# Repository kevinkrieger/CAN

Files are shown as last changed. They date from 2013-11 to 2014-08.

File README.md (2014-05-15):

Git repo for obd2-CAN board.

* obd2/ directory contains the KiCAD files
* lpcxpresso/ directory contains the files required to build firmware with lpcxpresso
* obd2_lpc1343/ is legacy directory when the 1343 was explored.
* reference/ contains CAN and obd2 and other reference material used in design
* video/ videos taken of design/build/test
* datasheets/ any datasheets of parts used or explored

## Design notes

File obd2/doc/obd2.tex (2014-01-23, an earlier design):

\documentclass{article}
% Allows control of page geometry
% Set to 1 inch margins (mla standard I guess)
\usepackage[margin=1in]{geometry}

% Graphics package
% Use it like:
% \begin{figure}[H]
% \centering
% \includegraphics[width=90mm,angle=0]{fixed_dome1.jpg}
% \caption{A simple caption}
% \label{overflow}
% \end{figure}	
\usepackage[pdftex]{graphicx}

% Allows you to include pdf documents or pages in the document
% using \includepdf[pages=2-4]{file} or whatever 
\usepackage{pdfpages}

% Self explanatory, appendix package
\usepackage{appendix}

% The listings package is used for inserting source code with highlights
\usepackage{listings}
\usepackage{color}
\lstdefinestyle{custom}{
  belowcaptionskip=1\baselineskip,
  language=bash,
  showstringspaces=false,
  basicstyle=\footnotesize\ttfamily,
  keywordstyle=\bfseries\color{green!40!black},
  commentstyle=\itshape\color{purple!40!black},
  identifierstyle=\color{blue},
  stringstyle=\color{orange},
  numberstyle=\ttfamily
}
\lstset{style=custom}

% Hyperref package is used for hyperlinking the document (ex: toc links)
\usepackage{hyperref}
\hypersetup{
    colorlinks,
    citecolor=black,
    filecolor=black,
    linkcolor=black,
    urlcolor=black
}

\usepackage{float}
\restylefloat{figure}

% Title Page
\title{CAN-obd2}
\author{Kevin Krieger}
\date{January 2014}

\begin{document}
\maketitle
\tableofcontents
\newpage

\section{History} \label{history}

\subsection{Version 1}

\begin{figure}[H]
\centering
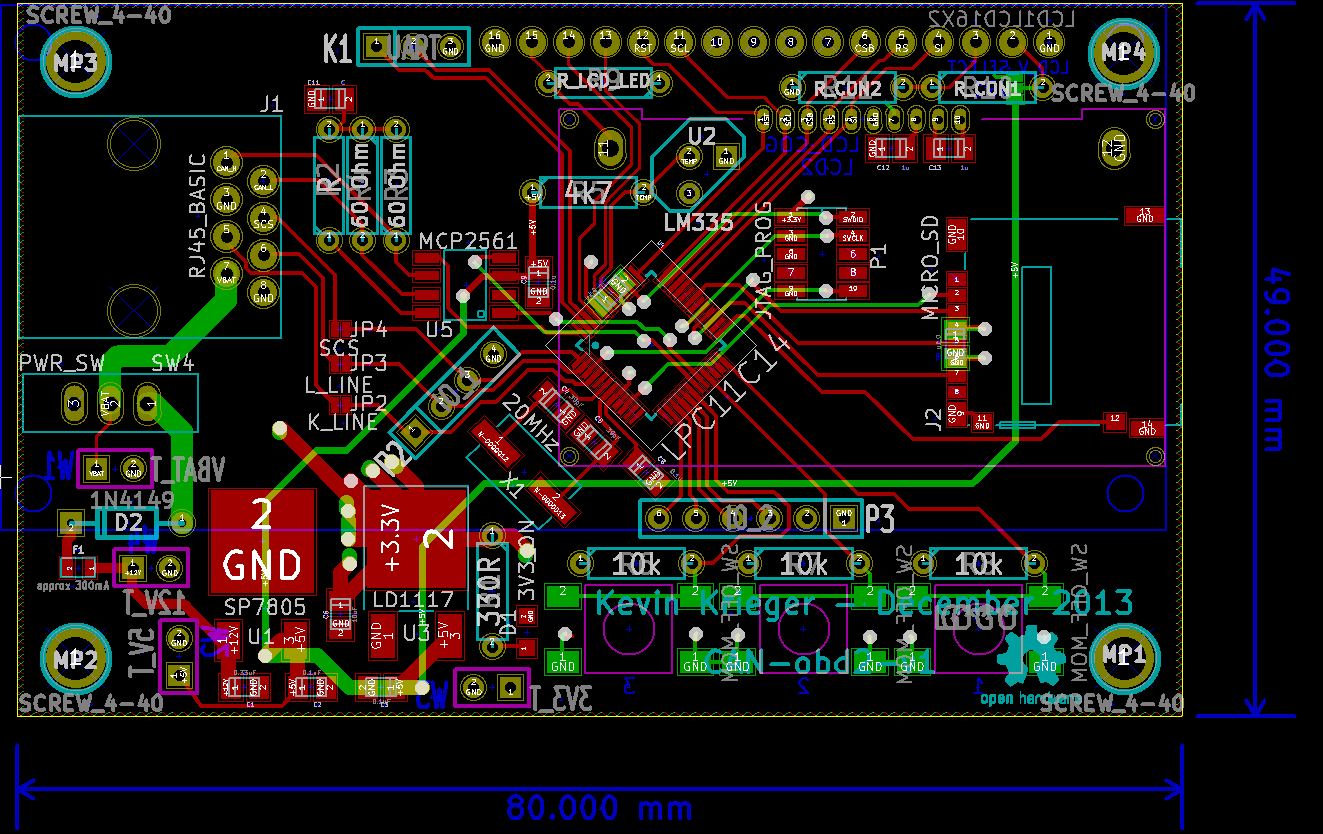
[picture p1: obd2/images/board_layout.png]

\caption{Board layout - Kicad}
\label{}
\end{figure}

\begin{figure}[H]
\centering
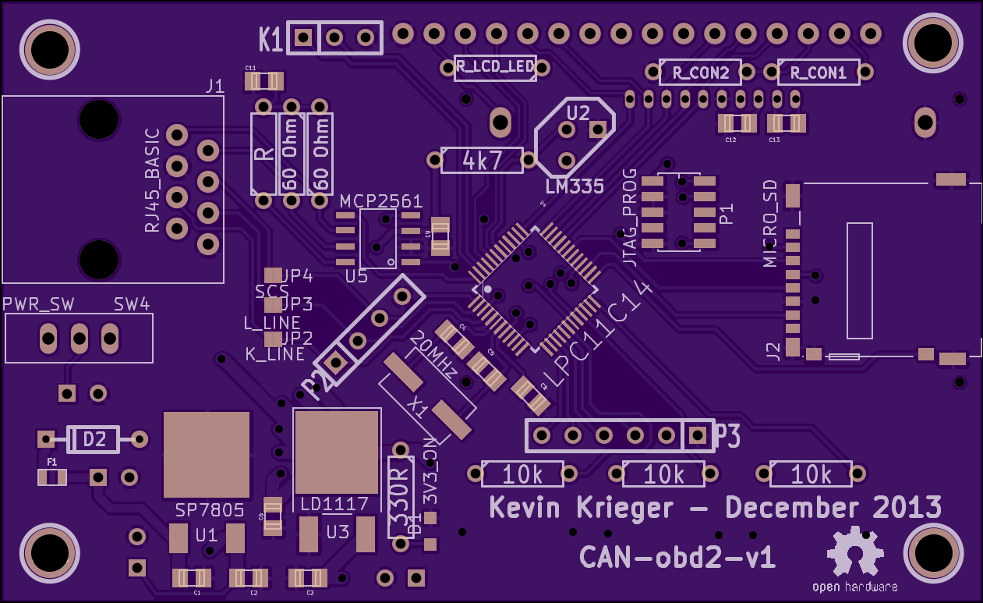
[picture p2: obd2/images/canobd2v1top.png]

\caption{oshpark.com top render}
\label{}
\end{figure}

\begin{figure}[H]
\centering
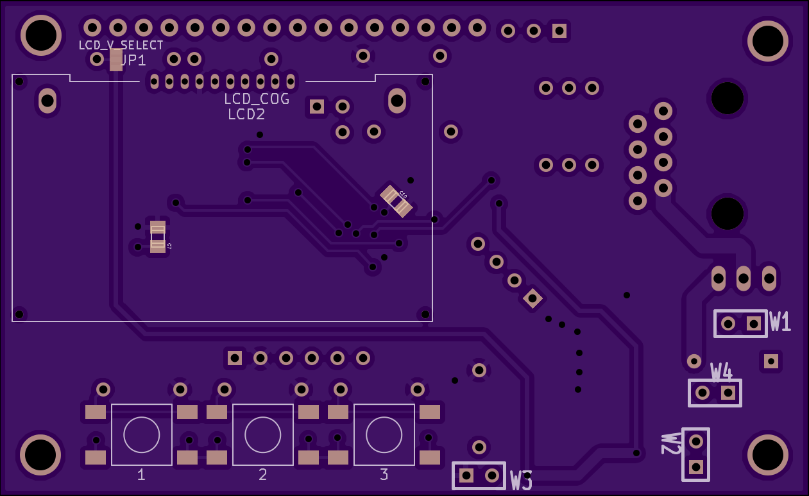
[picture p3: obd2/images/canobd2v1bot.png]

\caption{oshpark.com bottom render}
\label{}
\end{figure}

\begin{figure}[H]
\centering
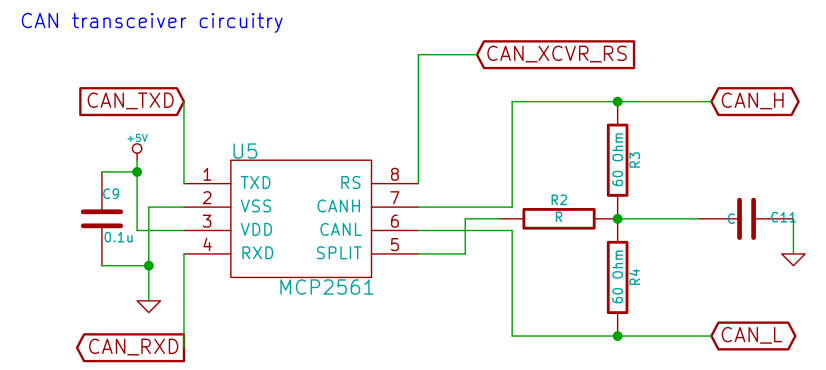
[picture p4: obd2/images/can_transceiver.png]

\caption{CAN transceiver circuitry}
\label{}
\end{figure}

\begin{figure}[H]
\centering
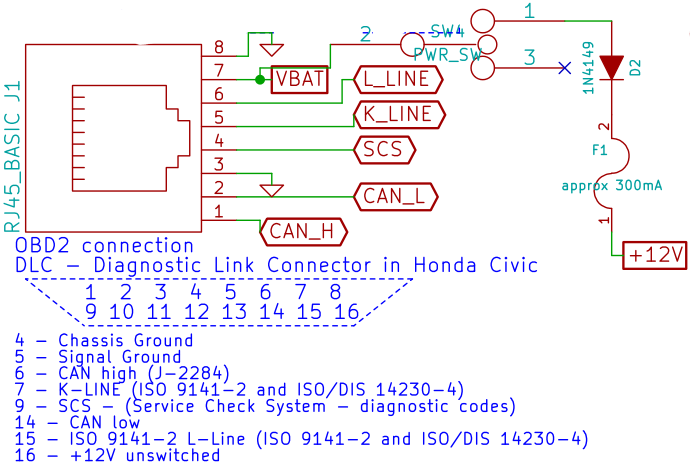
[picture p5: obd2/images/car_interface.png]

\caption{Interface to automobile data port (2008 Honda Civic)}
\label{}
\end{figure}

\begin{figure}[H]
\centering
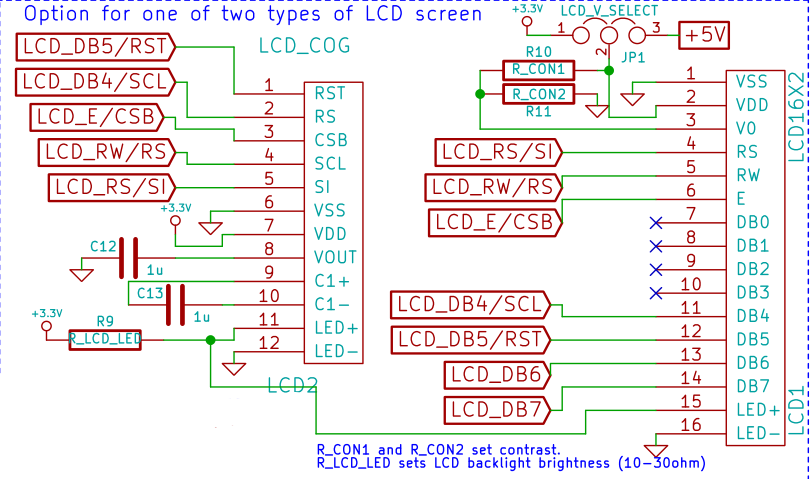
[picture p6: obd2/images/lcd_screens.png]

\caption{Two LCD screen options - circuitry}
\label{}
\end{figure}

\begin{figure}[H]
\centering
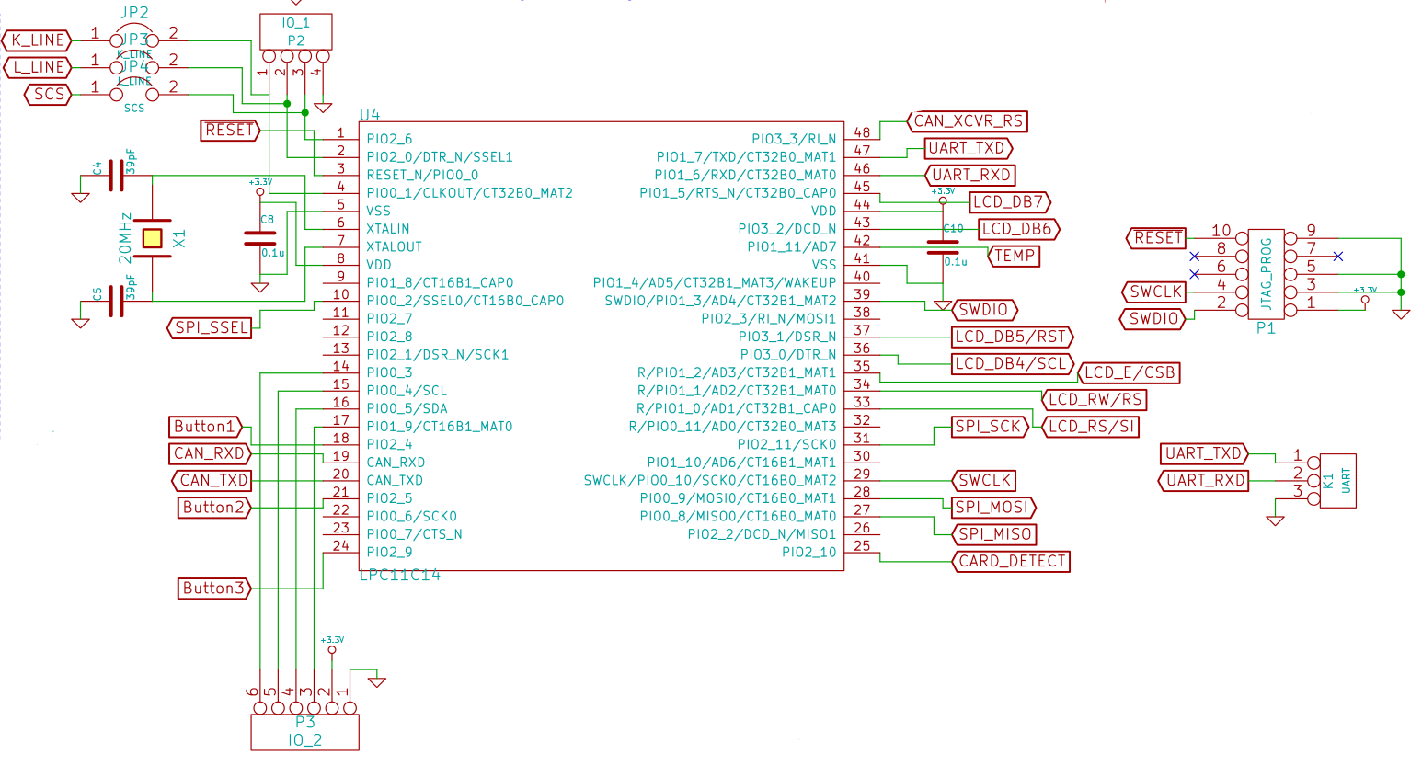
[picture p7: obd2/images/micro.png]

\caption{Microcontroller circuitry, IO connectors and programming port}
\label{}
\end{figure}

\begin{figure}[H]
\centering
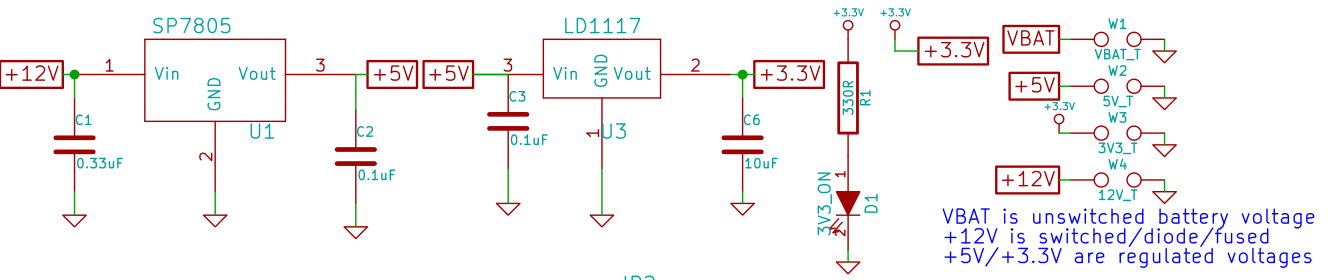
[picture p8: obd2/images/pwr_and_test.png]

\caption{Power and test point circuitry}
\label{}
\end{figure}

\begin{figure}[H]
\centering
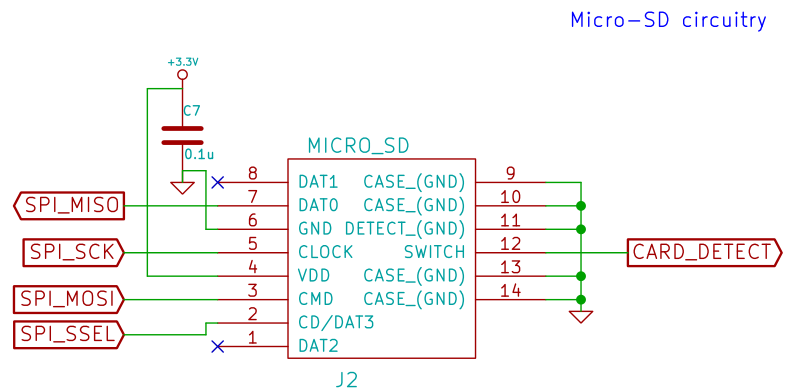
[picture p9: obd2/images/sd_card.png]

\caption{Micro SD card circuitry - SPI mode}
\label{}
\end{figure}

\begin{figure}[H]
\centering
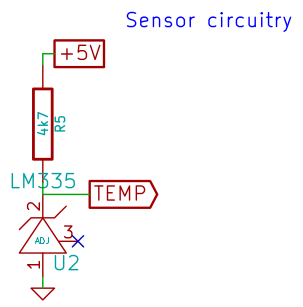
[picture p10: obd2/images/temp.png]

\caption{Temperature sensor circuit}
\label{}
\end{figure}

\begin{figure}[H]
\centering
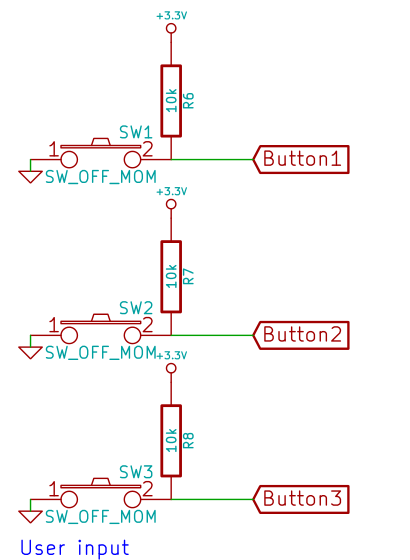
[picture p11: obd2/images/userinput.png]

\caption{User input circuitry}
\label{}
\end{figure}

\section{} \label{}

\section{} \label{}

\section{} \label{}

\section{} \label{}

\section{} \label{}

\section{} \label{}

%{%
%\newcommand{\mc}[3]{\multicolumn{#1}{#2}{#3}}
%\begin{center}
%\begin{tabular}[c]{|l|l|l|l|}\hline
%\mc{1}{|c|}{\textbf{Column 1}} & \mc{1}{c|}{\textbf{2}} & \mc{1}{c|}{\textbf%{3}} & \mc{1}{c|}{\textbf{4}}\\\hline
%Blah & Blah & blah 3 & \\
%Saskatchewan & Kevin Krieger & kevin.krieger@usask.ca & no info\\
%& & not much here &\\
%\hline
%\end{tabular}
%\end{center}
%}%

%{\bf THIS TEXT WILL BE LOUD!}

%\subsubsection{Subsubsection} \label{Labelsubsubsection}
%See the  \hyperref[overview]{Overview} section.

\appendix

\end{document}

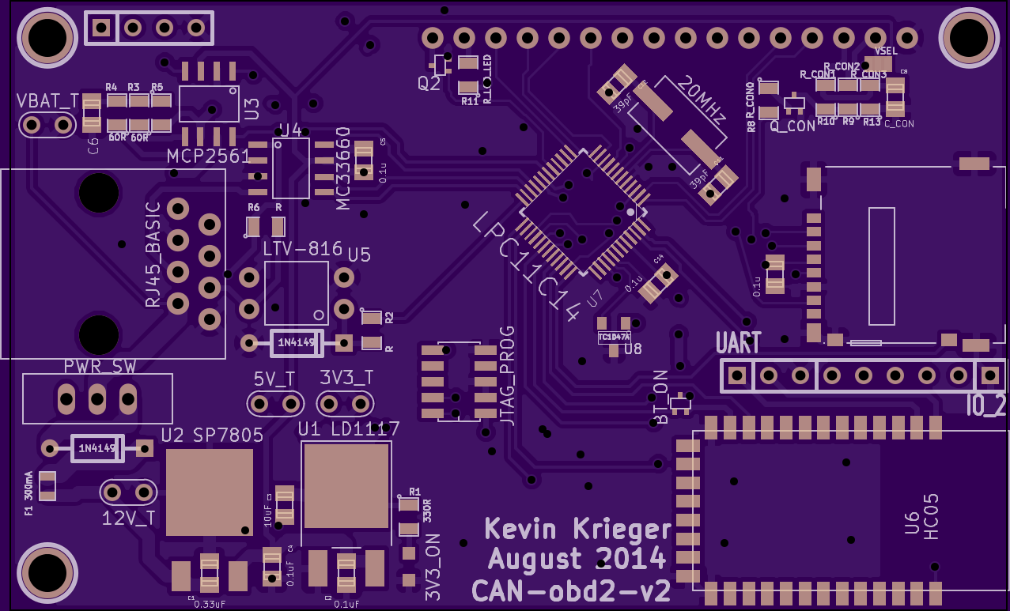
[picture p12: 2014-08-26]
obd2-v2/images/CANobd2v2_top.png

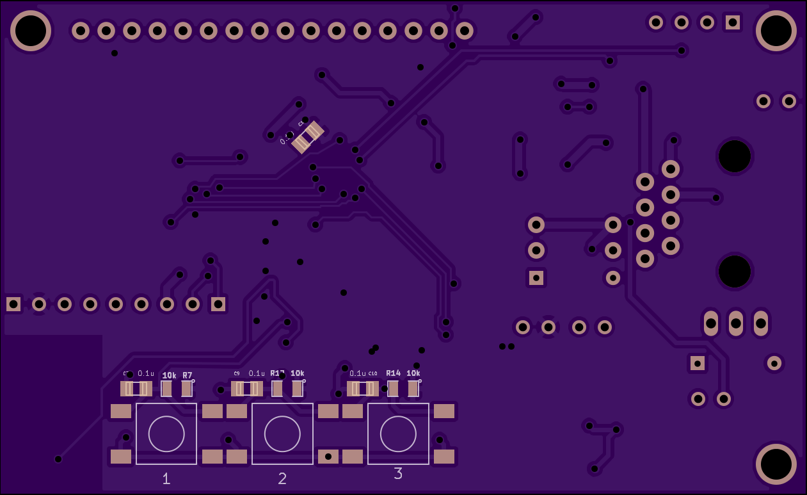
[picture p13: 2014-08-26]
obd2-v2/images/CANobd2v2_bot.png

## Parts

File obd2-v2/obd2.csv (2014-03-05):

ref | value | footprint
C1 | 0.33uF | c_0805
C2 | 0.1uF | c_0805
C3 | 0.1uF | c_0805
C4 | 39pF | c_0805
C5 | 39pF | c_0805
C6 | 10uF | c_0805
C7 | 0.1u | c_0805
C8 | 0.1u | c_0805
C9 | 0.1u | c_0805
C10 | 0.1u | c_0805
C11 | C | c_0805
C12 | 1u | c_0805
C13 | 1u | c_0805
D1 | 3V3_ON | LED_J_LEAD
D2 | 1N4149 | DO-35
F1 | approx 300mA | SM0603
J1 | RJ45_BASIC | RJ45
J2 | MICRO_SD | SD_502702_003
JP1 | LCD_V_SELECT | SOLDER_JUMPER_3
JP2 | K_LINE | SOLDER_JUMPER
JP3 | L_LINE | SOLDER_JUMPER
JP4 | SCS | SOLDER_JUMPER
K1 | UART | SIL-3
LCD1 | LCD16X2 | GDM1602K
LCD2 | LCD_COG | NHD_C0216CZ_NSW_BBW
MP1 | SCREW_4-40 | 1pin
MP2 | SCREW_4-40 | 1pin
MP3 | SCREW_4-40 | 1pin
MP4 | SCREW_4-40 | 1pin
P1 | JTAG_PROG | GRPB052VWQS-RC
P2 | IO_1 | SIL-4
P3 | IO_2 | SIL-6
R1 | 330R | R3
R2 | R | R3
R3 | 60 Ohm | R3
R4 | 60 Ohm | R3
R5 | 4k7 | R3
R6 | 10k | R3
R7 | 10k | R3
R8 | 10k | R3
R9 | R_LCD_LED | R3
R10 | R_CON1 | R3
R11 | R_CON2 | R3
SW1 | SW_OFF_MOM | FSM4JSMA_pushbutton
SW2 | SW_OFF_MOM | FSM4JSMA_pushbutton
SW3 | SW_OFF_MOM | FSM4JSMA_pushbutton
SW4 | PWR_SW | MMS1208
U1 | SP7805 | TO-252-3
U2 | LM335 | TO92
U3 | LD1117 | DPAK
U4 | LPC11C14 | LQFP48
U5 | MCP2561 | SOIC-8-Narrow
W1 | VBAT_T | SIL-2
W2 | 5V_T | SIL-2
W3 | 3V3_T | SIL-2
W4 | 12V_T | SIL-2
X1 | 20MHz | CSM-3X

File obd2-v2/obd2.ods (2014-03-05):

ref | value | footprint | part | Notes
C1 | 0.33uF | c_0805 | CC0805KKX7R8BB105 | don't have a .33uF, so use 1uF
C2 | 0.1uF | c_0805 | CL21F104ZBCNNNC
C3 | 0.1uF | c_0805 | CL21F104ZBCNNNC
C4 | 39pF | c_0805 | CL21C390JBANNNC
C5 | 39pF | c_0805 | CL21C390JBANNNC
C6 | 10uF | c_0805 | LMK212B7106KG-TD
C7 | 0.1u | c_0805 | CL21F104ZBCNNNC
C8 | 0.1u | c_0805 | CL21F104ZBCNNNC
C9 | 0.1u | c_0805 | CL21F104ZBCNNNC
C10 | 0.1u | c_0805 | CL21F104ZBCNNNC
C11 | C | c_0805 |  | Don't populate unless you need to
C12 | 1u | c_0805 | CC0805KKX7R8BB105 | Don't populate unless using GDM1602K
C13 | 1u | c_0805 | CC0805KKX7R8BB105 | Don't populate unless using GDM1602K
D1 | 3V3_ON | LED_J_LEAD | LG M67K-G1J2-24-Z | Don't populate unless using GDM1602K
D2 | 1N4149 | DO-35 | 1N4149TR
F1 | approx 300mA | SM0603 | 0603SFV050F/32-2CT-ND | it's 500mA, which should be PLENTY
J1 | RJ45_BASIC | RJ45 | 54602-908LF
J2 | MICRO_SD | SD_502702_003 | 5027020891 | the pads could be a bit larger away from the body of the device.
JP1 | LCD_V_SELECT | SOLDER_JUMPER_3
JP2 | K_LINE | SOLDER_JUMPER
JP3 | L_LINE | SOLDER_JUMPER
JP4 | SCS | SOLDER_JUMPER
K1 | UART | SIL-3
LCD1 | LCD16X2 | GDM1602K |  | Definitely need the A and K pins to be wider, and the rest of the pins should be a bit bigger. I used a hobby knife to cut them down to size a bit. *** THE A/K pins ARE OK, BUT THE OTHERS ARE ALL BACKWARDS!!! ***
LCD2 | LCD_COG | NHD_C0216CZ_NSW_BBW
MP1 | SCREW_4-40 | 1pin
MP2 | SCREW_4-40 | 1pin
MP3 | SCREW_4-40 | 1pin
MP4 | SCREW_4-40 | 1pin
P1 | JTAG_PROG | GRPB052VWQS-RC | FFSD-05-D-06.00-01-N
P2 | IO_1 | SIL-4
P3 | IO_2 | SIL-6
R1 | 330R | R3
R2 | R | R3 |  | Don't populate unless you need to
R3 | 60 Ohm | R3 | MFR-25FBF52-59R | Couldn't find 60 ohm, so 59 ohm is where it's at.
R4 | 60 Ohm | R3 | MFR-25FBF52-59R | Couldn't find 60 ohm, so 59 ohm is where it's at.
R5 | 4k7 | R3 |  | Actually using 5.6K
R6 | 10k | R3 |  | Don't populate unless you need to
R7 | 10k | R3 |  | Don't populate unless you need to
R8 | 10k | R3 |  | Don't populate unless you need to
R9 | R_LCD_LED | R3 |  | Using 18Ohm to start, sets LED backlight brightness.
R10 | R_CON1 | R3 |  | Don't populate unless using 16 pin LCD
R11 | R_CON2 | R3 |  | Don't populate unless using 16 pin LCD
SW1 | SW_OFF_MOM | FSM4JSMA_pushbutton | FSM4JSMA
SW2 | SW_OFF_MOM | FSM4JSMA_pushbutton | FSM4JSMA
SW3 | SW_OFF_MOM | FSM4JSMA_pushbutton | FSM4JSMA
SW4 | PWR_SW | MMS1208 | MMS1208
U1 | SP7805 | TO-252-3 | SP7805V2-L/TR
U2 | LM335 | TO92 | SEN-09438
U3 | LD1117 | DPAK | LD1117DT33TR
U4 | LPC11C14 | LQFP48 | lpc11c14
U5 | MCP2561 | SOIC-8-Narrow | mcp256
W1 | VBAT_T | SIL-2
W2 | 5V_T | SIL-2
W3 | 3V3_T | SIL-2
W4 | 12V_T | SIL-2
X1 | 20MHz | CSM-3X | ECS-200-20-3X-EN-TR | takes 39pF capacitors

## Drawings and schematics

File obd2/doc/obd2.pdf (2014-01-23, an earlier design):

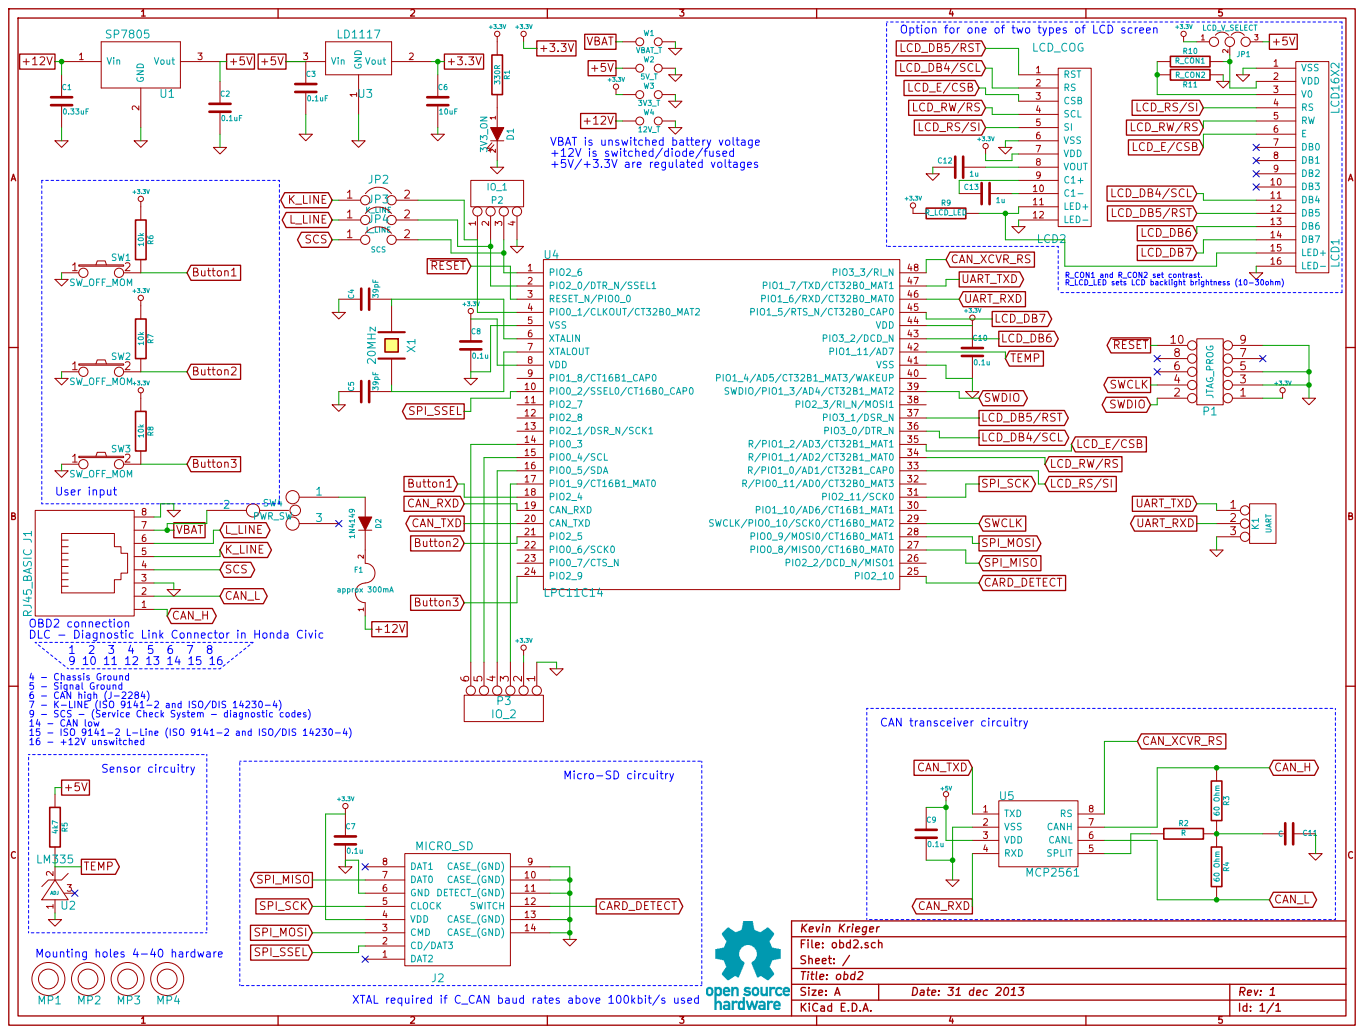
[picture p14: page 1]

+3.3V Option for one of two types of LCD screen
LCD_DB5/RST
LCD_DB4/SCL
LCD_E/CSB

R10 R_CON1 R11 R_CON2 R_CON1 and R_CON2 set contrast. R_LCD_LED sets LCD backlight brightness (10-30ohm) VBAT is unswitched battery voltage

+12V is switched/diode/fused

OBD2 connection
DLC - Diagnostic Link Connector in Honda Civic

4 - Chassis Ground
5 - Signal Ground
6 - CAN high (J-2284)
7 - K-LINE (ISO 9141-2 and ISO/DIS 14230-4)
9 - SCS - (Service Check System - diagnostic codes) 14 - CAN low

Sensor circuitry

Micro-SD circuitry

Id: 1/1 Title: obd2 File: obd2.sch Sheet: /

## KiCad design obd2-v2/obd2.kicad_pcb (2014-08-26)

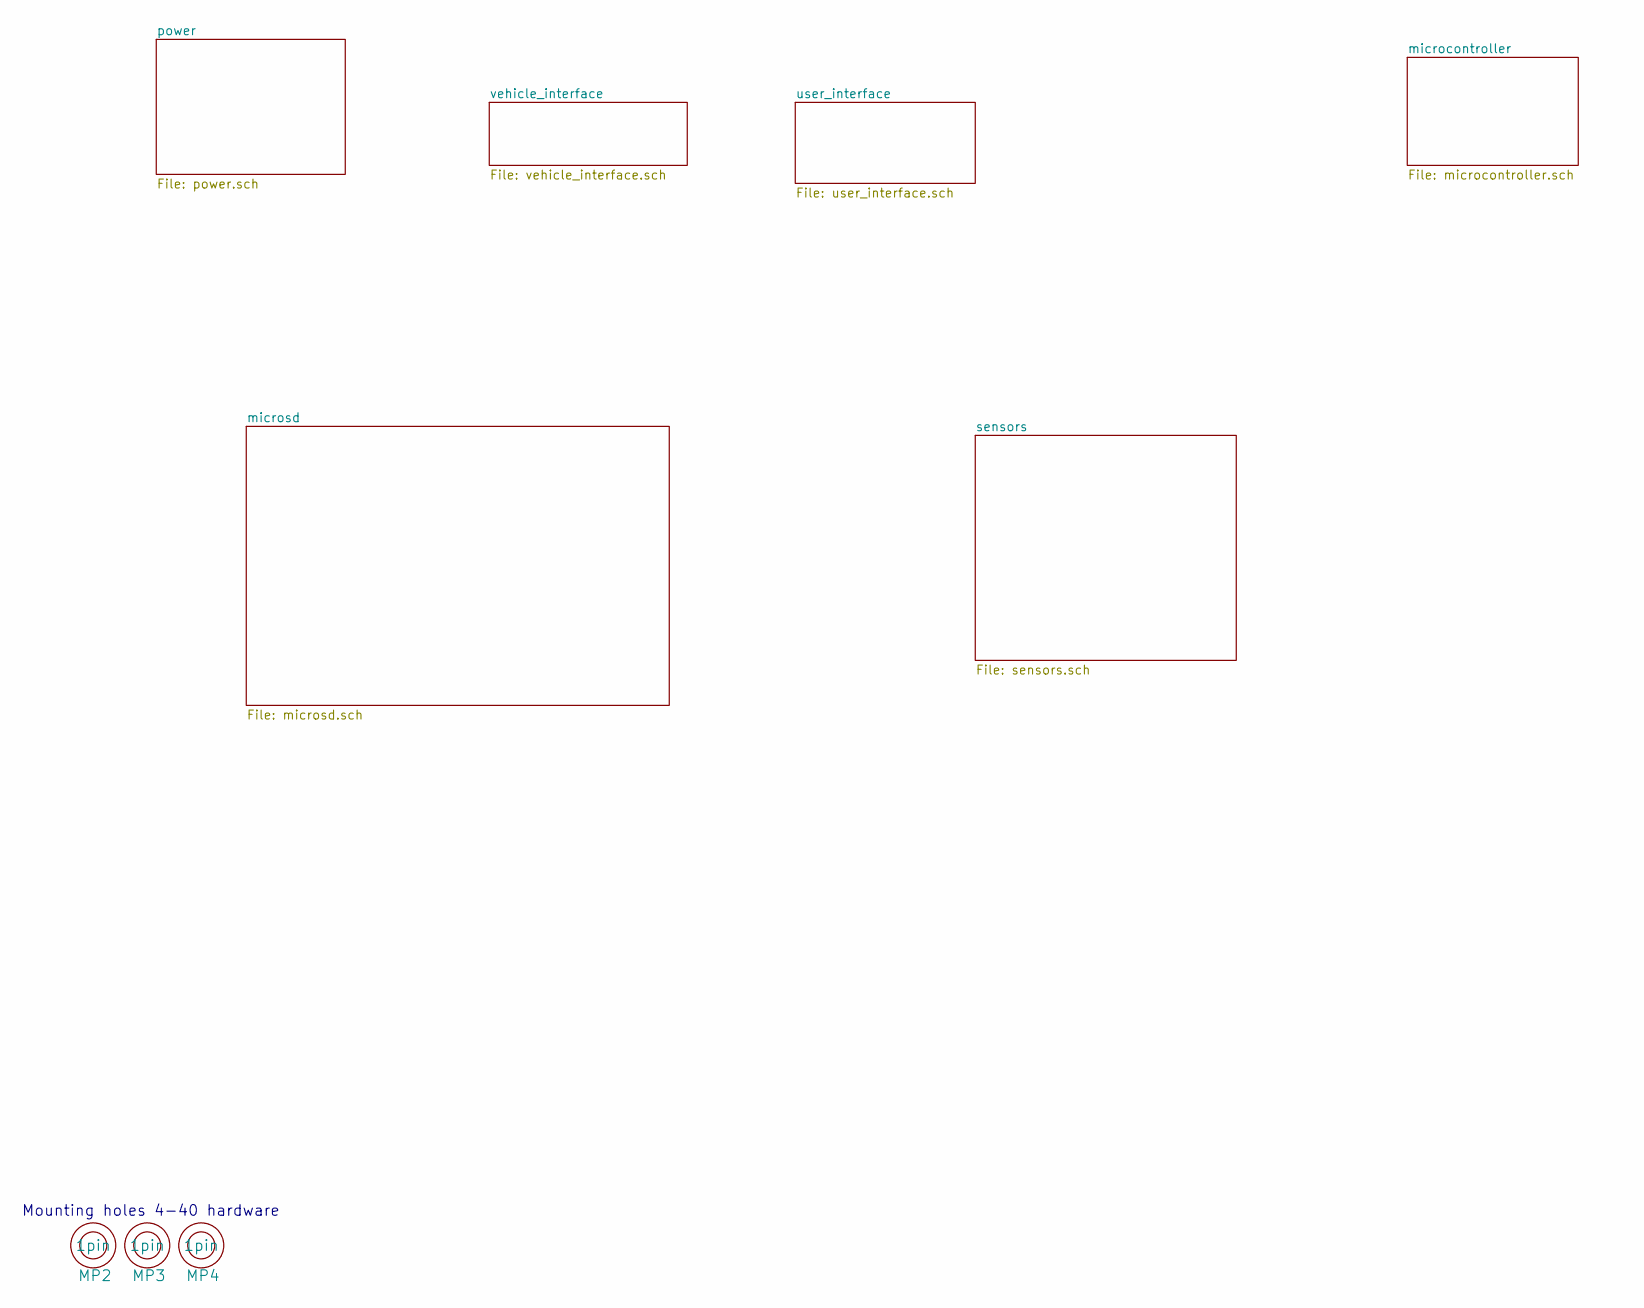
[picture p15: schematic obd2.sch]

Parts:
MP2, MP3, MP4: SCREW_4-40; 1pin

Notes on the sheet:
Mounting holes 4-40 hardware

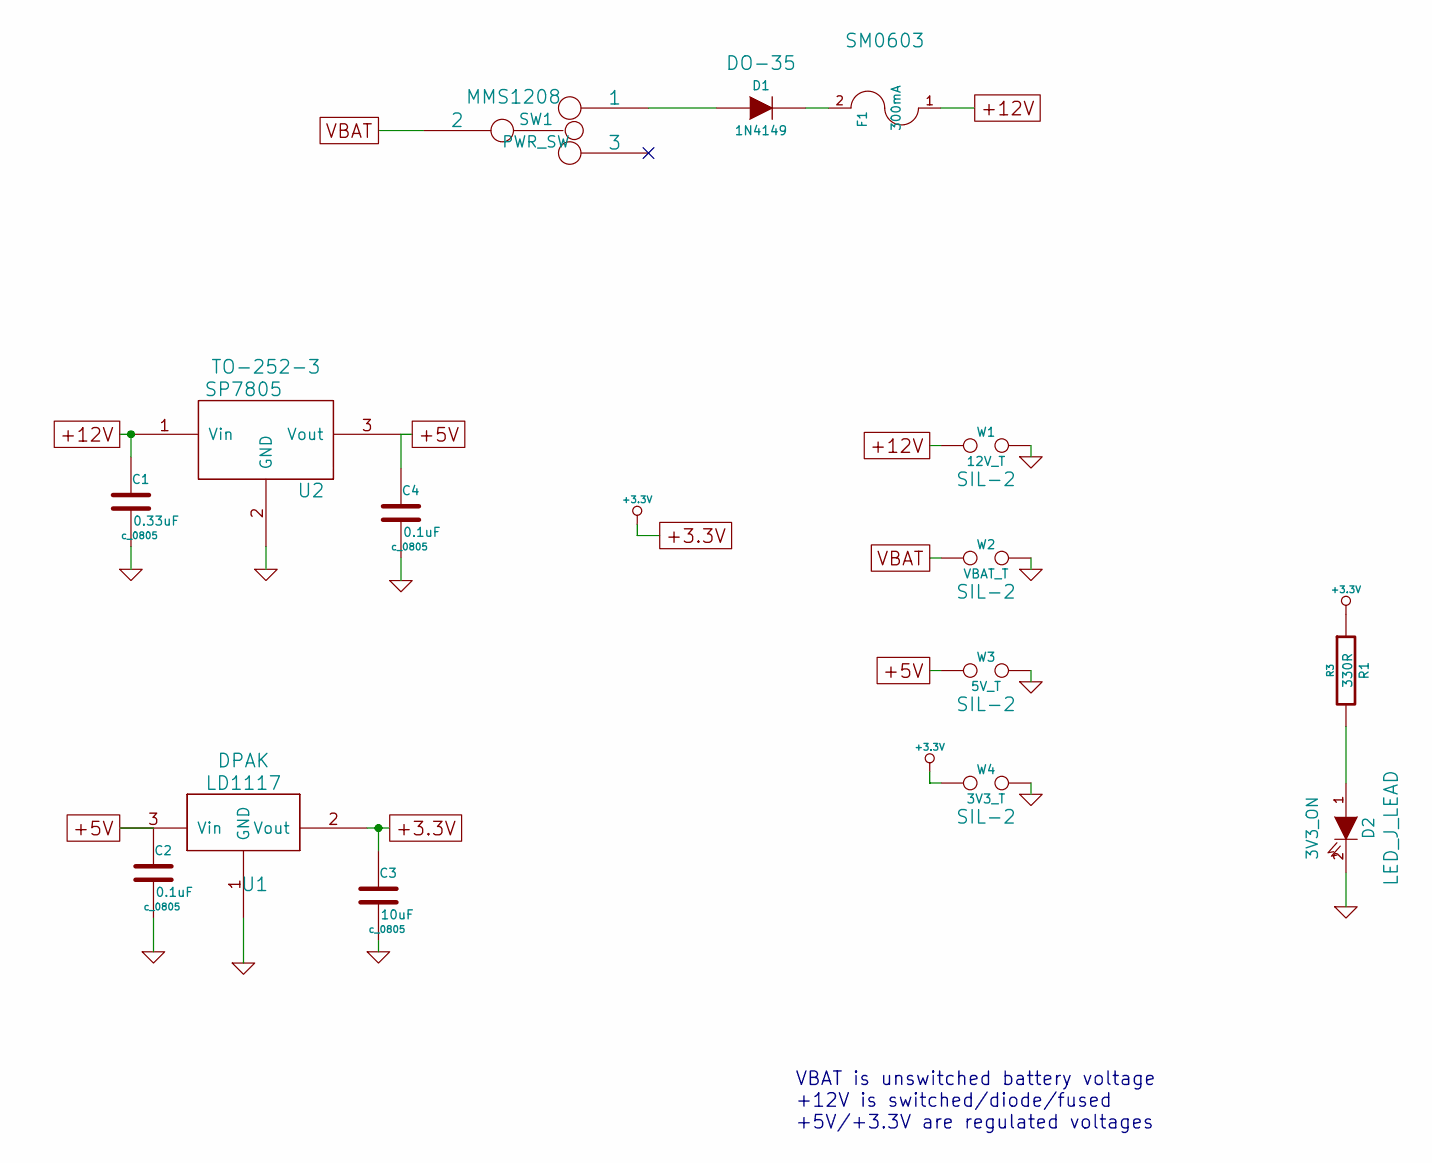
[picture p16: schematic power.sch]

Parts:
C1: 0.33uF; c_0805
C2, C4: 0.1uF; c_0805
C3: 10uF; c_0805
D1: 1N4149; DO-35
D2: 3V3_ON; LED_J_LEAD
F1: 300mA; SM0603
R1: 330R; R3
SW1: PWR_SW; MMS1208
U1: LD1117; DPAK
U2: SP7805; TO-252-3
W1: 12V_T; SIL-2
W2: VBAT_T; SIL-2
W3: 5V_T; SIL-2
W4: 3V3_T; SIL-2

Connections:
+3.3V: C3.1, R1.1, U1.2 (Vout), W4.1; also elsewhere on the board
+5V: C2.1, C4.1, U1.3 (Vin), U2.3 (Vout), W3.1; also elsewhere on the board
+12V: C1.1, F1.1, U2.1 (Vin), W1.1; also elsewhere on the board
GND: C1.2, C2.2, C3.2, C4.2, D2.2 (K), U1.1 (GND), U2.2 (GND), W1.2, W2.2, W3.2, W4.2; also elsewhere on the board
unnamed: D1.2 (K), F1.2
unnamed: D1.1 (A), SW1.1
unnamed: D2.1 (A), R1.2
VBAT: SW1.2, W2.1; also elsewhere on the board

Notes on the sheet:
VBAT is unswitched battery voltage +12V is switched/diode/fused +5V/+3.3V are regulated voltages

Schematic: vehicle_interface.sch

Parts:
C5: 0.1u; c_0805
C6: C; c_0805
D3: 1N4149
J1: RJ45_BASIC; RJ45
R2, R6: R
R3: R; R3
R4, R5: 60R; R3
U3: MCP2561; SOIC-8-Narrow
U4: MC33660
U5: LTV-816

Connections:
+5V: C5.1, U3.3 (VDD), U4.7 (VDD); also elsewhere on the board
+12V: R6.1, U4.1 (VBB); also elsewhere on the board
CAN_H: J1.1, R4.1, U3.7 (CANH)
CAN_L: J1.2, R5.2, U3.6 (CANL)
CAN_RXD: U3.4 (RXD); also elsewhere on the board
CAN_TXD: U3.1 (TXD); also elsewhere on the board
CAN_XCVR_RS: U3.8 (RS); also elsewhere on the board
GND: C5.2, C6.1, D3.1 (A), J1.3, J1.8, U3.2 (VSS), U4.3 (GND), U5.2 (K), U5.3 (E); also elsewhere on the board
K_LINE: J1.5, U4.4 (ISO)
K_LINE_EN: U4.8 (CEN); also elsewhere on the board
K_LINE_RX: U4.6 (RX); also elsewhere on the board
K_LINE_TX: U4.5 (TX); also elsewhere on the board
L_LINE: J1.6, R6.2, U5.4 (C)
L_LINE_CONTROL: R2.1; also elsewhere on the board
unnamed: D3.2 (K), R2.2, U5.1 (A)
unnamed: C6.2, R3.2, R4.2, R5.1
unnamed: R3.1, U3.5 (SPLIT)
VBAT: J1.7; also elsewhere on the board

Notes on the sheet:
OBD2 connection DLC - Diagnostic Link Connector in Honda Civic
1 2 3 4 5 6 7 8 9 10 11 12 13 14 15 16
4 - Chassis Ground 5 - Signal Ground 6 - CAN high (J-2284) 7 - K-LINE (ISO 9141-2 and ISO/DIS 14230-4) 9 - SCS - (Service Check System - diagnostic codes) 14 - CAN low 15 - ISO 9141-2 L-Line (ISO 9141-2 and ISO/DIS 14230-4) 16 - +12V unswitched
60 Ohm termination resistors only populated if board is end of CAN bus
L-line is unidirectional and used for initialization only. Optoisolation isolates the vehicle's L-Line from the microcontroller. Diode protects optoisolator from reverse voltages. See "INITIALIZING COMMUNICATION TO VEHICLE OBDII SYSTEM" by Peter Dzhelekarski, Dimiter Alexiev

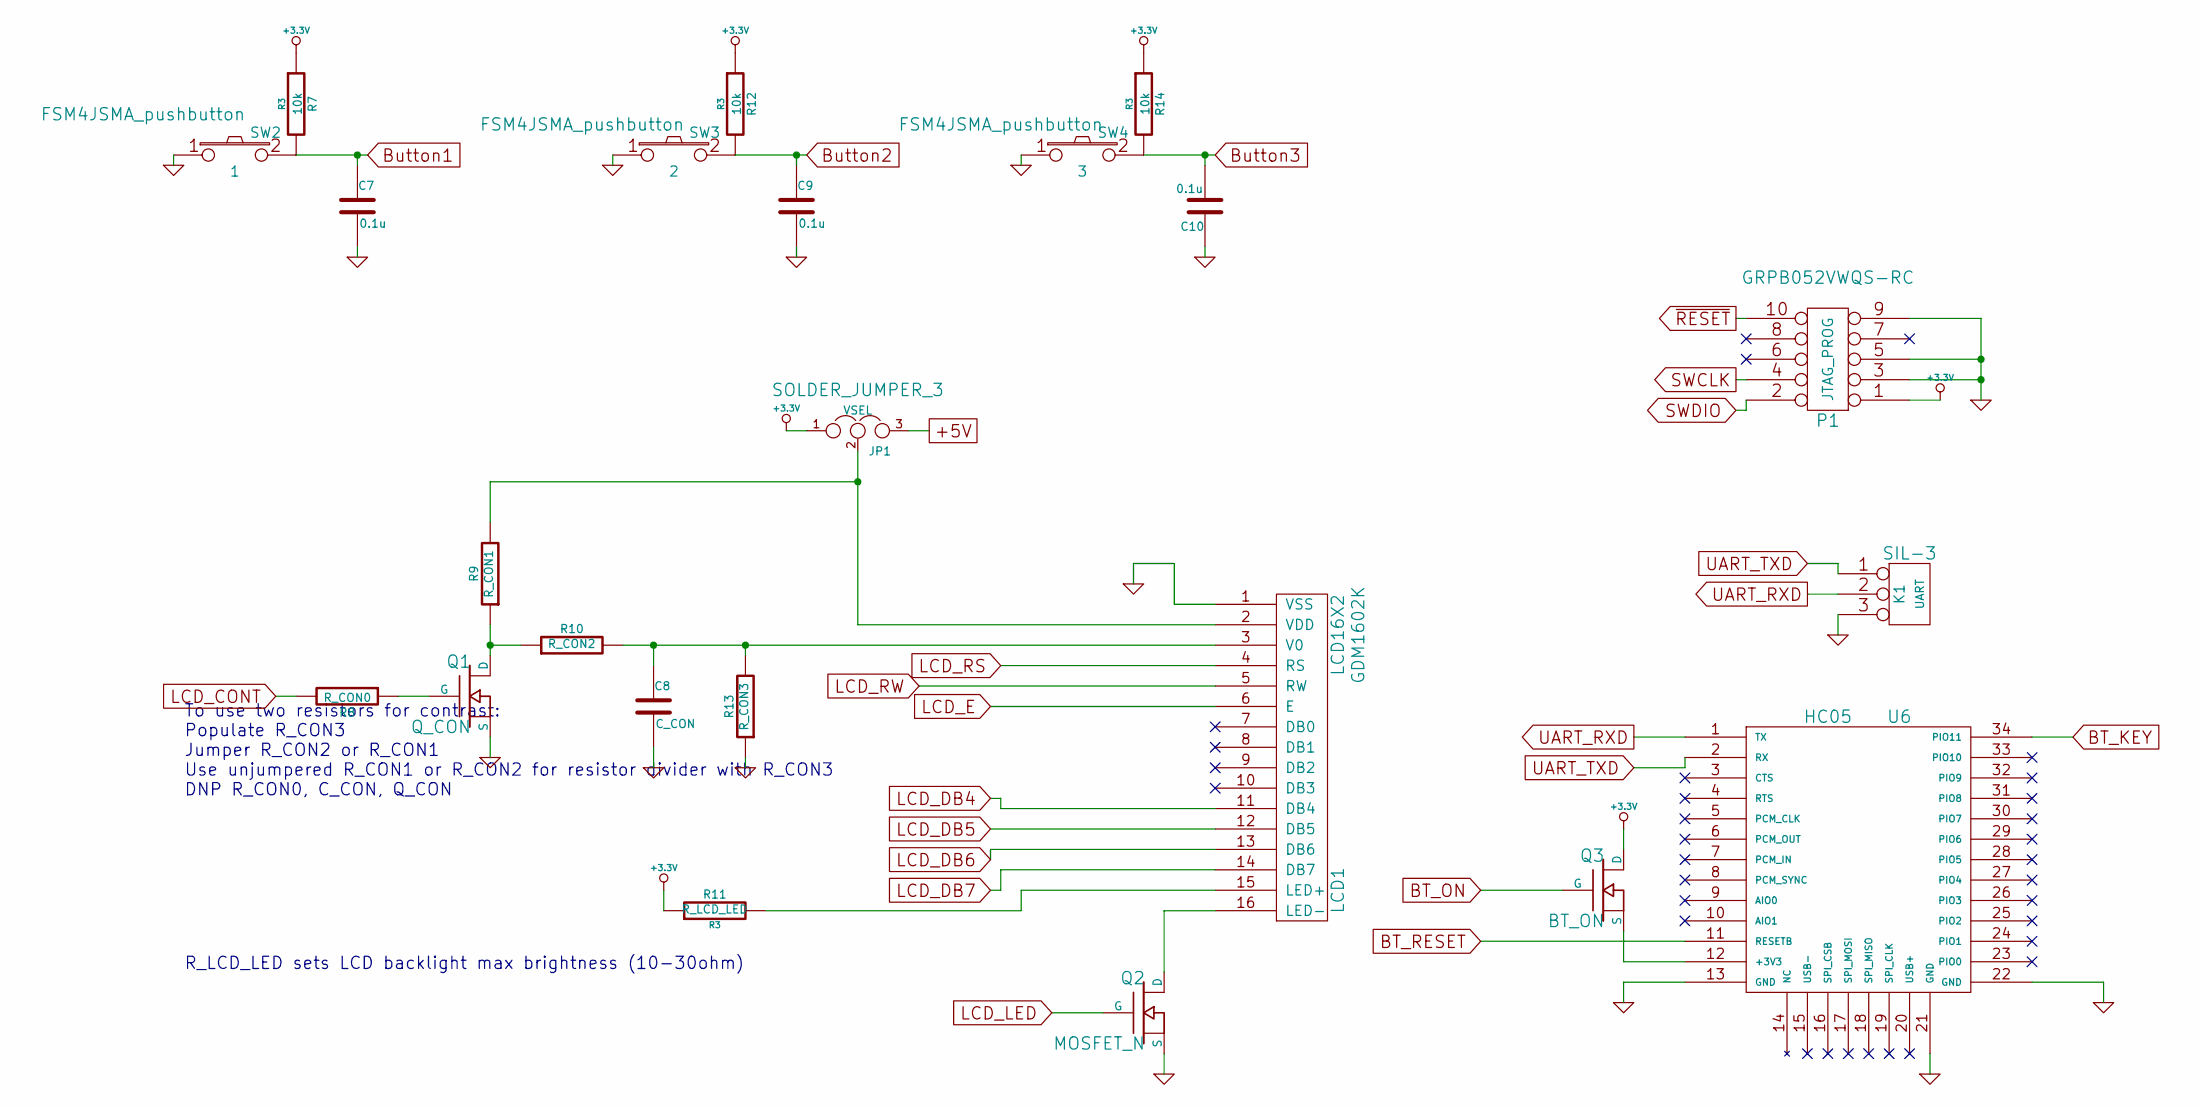
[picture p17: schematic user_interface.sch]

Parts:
C7, C9, C10: 0.1u
C8: C_CON
JP1: VSEL; SOLDER_JUMPER_3
K1: UART; SIL-3
LCD1: LCD16X2; GDM1602K
P1: JTAG_PROG; GRPB052VWQS-RC
Q1: Q_CON
Q2: MOSFET_N
Q3: BT_ON
R7, R12, R14: 10k; R3
R8: R_CON0
R9: R_CON1
R10: R_CON2
R11: R_LCD_LED; R3
R13: R_CON3
SW2: 1; FSM4JSMA_pushbutton
SW3: 2; FSM4JSMA_pushbutton
SW4: 3; FSM4JSMA_pushbutton
U6: HC05

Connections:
+3.3V: JP1.1, P1.1, Q3.D, R7.1, R11.1, R12.1, R14.1; also elsewhere on the board
+5V: JP1.3; also elsewhere on the board
BT_KEY: U6.34 (PIO11); also elsewhere on the board
BT_ON: Q3.G; also elsewhere on the board
BT_RESET: U6.11 (RESETB); also elsewhere on the board
Button1: C7.1, R7.2, SW2.2; also elsewhere on the board
Button2: C9.1, R12.2, SW3.2; also elsewhere on the board
Button3: C10.2, R14.2, SW4.2; also elsewhere on the board
GND: C7.2, C8.2, C9.2, C10.1, K1.3, LCD1.1 (VSS), P1.3, P1.5, P1.9, Q1.S, Q2.S, R13.1, SW2.1, SW3.1, SW4.1, U6.13 (GND), U6.21 (GND), U6.22 (GND); also elsewhere on the board
LCD_CONT: R8.2; also elsewhere on the board
LCD_DB4: LCD1.11 (DB4); also elsewhere on the board
LCD_DB5: LCD1.12 (DB5); also elsewhere on the board
LCD_DB6: LCD1.13 (DB6); also elsewhere on the board
LCD_DB7: LCD1.14 (DB7); also elsewhere on the board
LCD_LED: Q2.G; also elsewhere on the board
LCD_RS: LCD1.4 (RS); also elsewhere on the board
LCD_RW: LCD1.5 (RW); also elsewhere on the board
unnamed: Q1.D, R9.1, R10.1
unnamed: Q3.S, U6.12 (+3V3)
unnamed: C8.1, LCD1.3 (V0), R10.2, R13.2
unnamed: JP1.2, LCD1.2 (VDD), R9.2
unnamed: Q1.G, R8.1
unnamed: LCD1.16 (LED-), Q2.D
unnamed: LCD1.15 (LED+), R11.2
SWCLK: P1.4; also elsewhere on the board
SWDIO: P1.2; also elsewhere on the board
UART_RXD: K1.2 (PM), U6.1 (TX); also elsewhere on the board
UART_TXD: K1.1, U6.2 (RX); also elsewhere on the board
~RESET: P1.10; also elsewhere on the board

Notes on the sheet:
R_LCD_LED sets LCD backlight max brightness (10-30ohm)
To use two resistors for contrast: Populate R_CON3 Jumper R_CON2 or R_CON1 Use unjumpered R_CON1 or R_CON2 for resistor divider with R_CON3 DNP R_CON0, C_CON, Q_CON

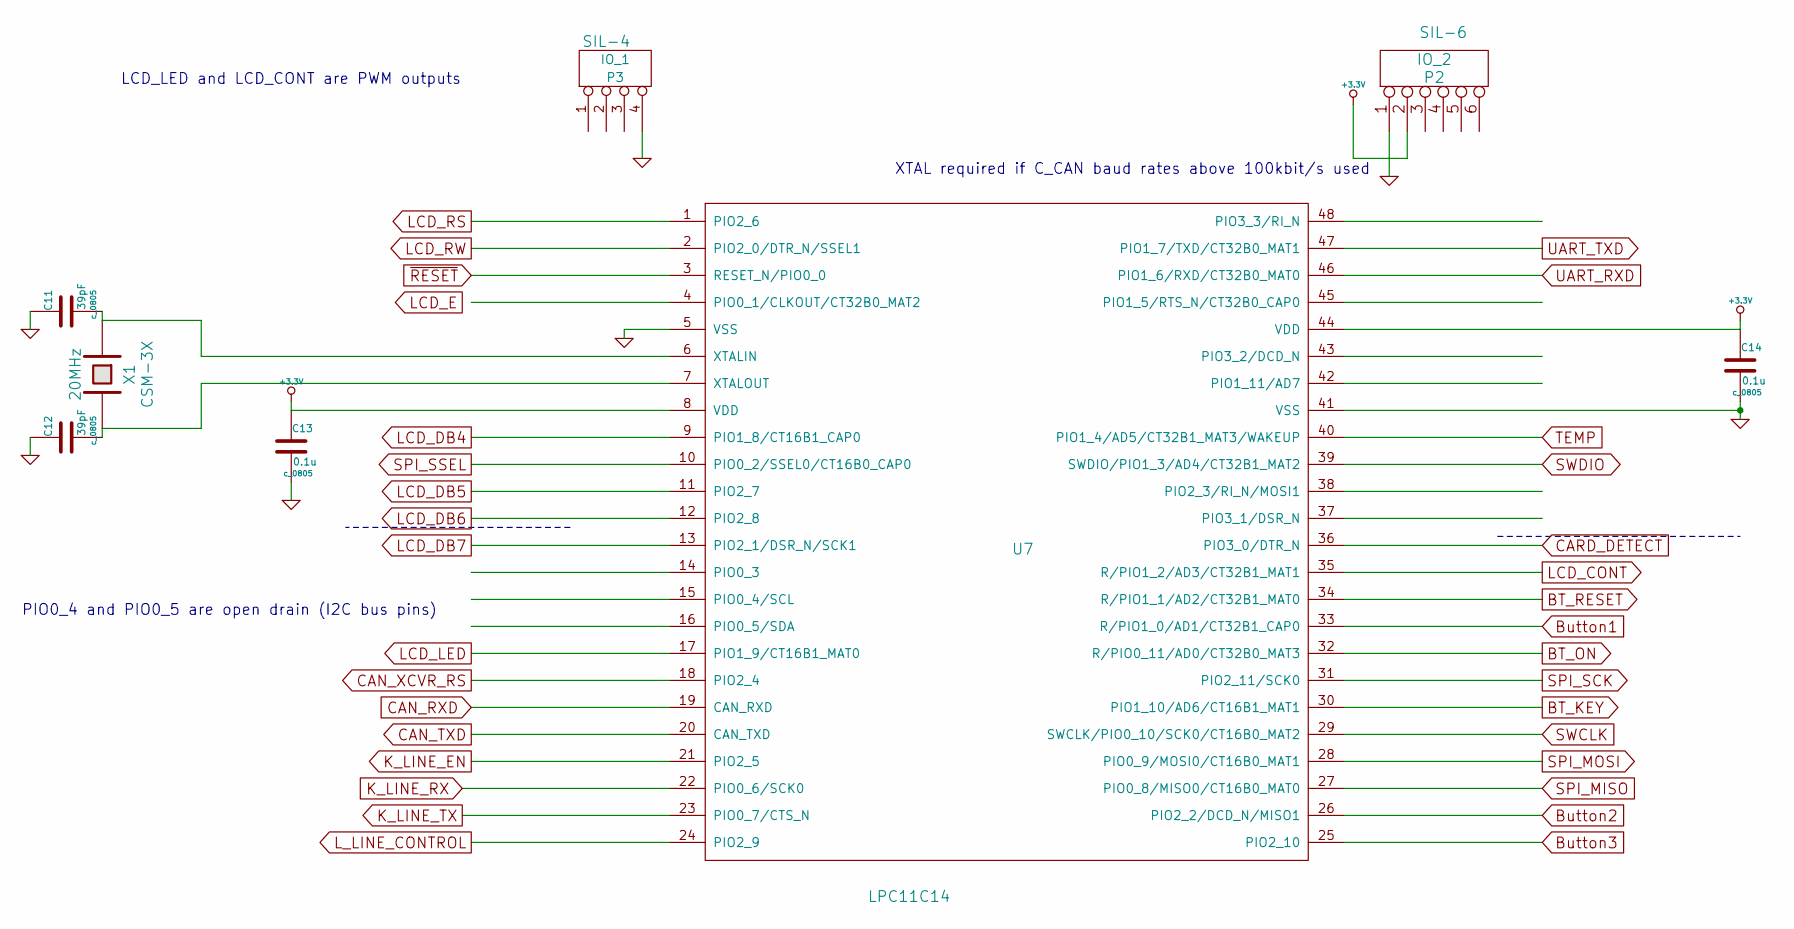
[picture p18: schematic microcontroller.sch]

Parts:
C11, C12: 39pF; c_0805
C13, C14: 0.1u; c_0805
P2: IO_2; SIL-6
P3: IO_1; SIL-4
U7: LPC11C14; LQFP48
X1: 20MHz; CSM-3X

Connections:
+3.3V: C13.1, C14.1, P2.2, U7.8 (VDD), U7.44 (VDD); also elsewhere on the board
BT_KEY: U7.30 (PIO1_10/AD6/CT16B1_MAT1); also elsewhere on the board
BT_ON: U7.32 (R/PIO0_11/AD0/CT32B0_MAT3); also elsewhere on the board
BT_RESET: U7.34 (R/PIO1_1/AD2/CT32B1_MAT0); also elsewhere on the board
Button1: U7.33 (R/PIO1_0/AD1/CT32B1_CAP0); also elsewhere on the board
Button2: U7.26 (PIO2_2/DCD_N/MISO1); also elsewhere on the board
Button3: U7.25 (PIO2_10); also elsewhere on the board
CAN_RXD: U7.19 (CAN_RXD); also elsewhere on the board
CAN_TXD: U7.20 (CAN_TXD); also elsewhere on the board
CAN_XCVR_RS: U7.18 (PIO2_4); also elsewhere on the board
CARD_DETECT: U7.36 (PIO3_0/DTR_N); also elsewhere on the board
GND: C11.1, C12.1, C13.2, C14.2, P2.1, P3.4, U7.5 (VSS), U7.41 (VSS); also elsewhere on the board
K_LINE_EN: U7.21 (PIO2_5); also elsewhere on the board
K_LINE_RX: U7.22 (PIO0_6/SCK0); also elsewhere on the board
K_LINE_TX: U7.23 (PIO0_7/CTS_N); also elsewhere on the board
LCD_CONT: U7.35 (R/PIO1_2/AD3/CT32B1_MAT1); also elsewhere on the board
LCD_DB4: U7.9 (PIO1_8/CT16B1_CAP0); also elsewhere on the board
LCD_DB5: U7.11 (PIO2_7); also elsewhere on the board
LCD_DB6: U7.12 (PIO2_8); also elsewhere on the board
LCD_DB7: U7.13 (PIO2_1/DSR_N/SCK1); also elsewhere on the board
LCD_LED: U7.17 (PIO1_9/CT16B1_MAT0); also elsewhere on the board
LCD_RS: U7.1 (PIO2_6); also elsewhere on the board
LCD_RW: U7.2 (PIO2_0/DTR_N/SSEL1); also elsewhere on the board
L_LINE_CONTROL: U7.24 (PIO2_9); also elsewhere on the board
unnamed: C12.2, U7.7 (XTALOUT), X1.2
unnamed: C11.2, U7.6 (XTALIN), X1.1
SPI_MISO: U7.27 (PIO0_8/MISO0/CT16B0_MAT0); also elsewhere on the board
SPI_MOSI: U7.28 (PIO0_9/MOSI0/CT16B0_MAT1); also elsewhere on the board
SPI_SCK: U7.31 (PIO2_11/SCK0); also elsewhere on the board
SPI_SSEL: U7.10 (PIO0_2/SSEL0/CT16B0_CAP0); also elsewhere on the board
SWCLK: U7.29 (SWCLK/PIO0_10/SCK0/CT16B0_MAT2); also elsewhere on the board
SWDIO: U7.39 (SWDIO/PIO1_3/AD4/CT32B1_MAT2); also elsewhere on the board
TEMP: U7.40 (PIO1_4/AD5/CT32B1_MAT3/WAKEUP); also elsewhere on the board
UART_RXD: U7.46 (PIO1_6/RXD/CT32B0_MAT0); also elsewhere on the board
UART_TXD: U7.47 (PIO1_7/TXD/CT32B0_MAT1); also elsewhere on the board
~RESET: U7.3 (RESET_N/PIO0_0); also elsewhere on the board

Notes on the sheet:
XTAL required if C_CAN baud rates above 100kbit/s used
LCD_LED and LCD_CONT are PWM outputs
PIO0_4 and PIO0_5 are open drain (I2C bus pins)

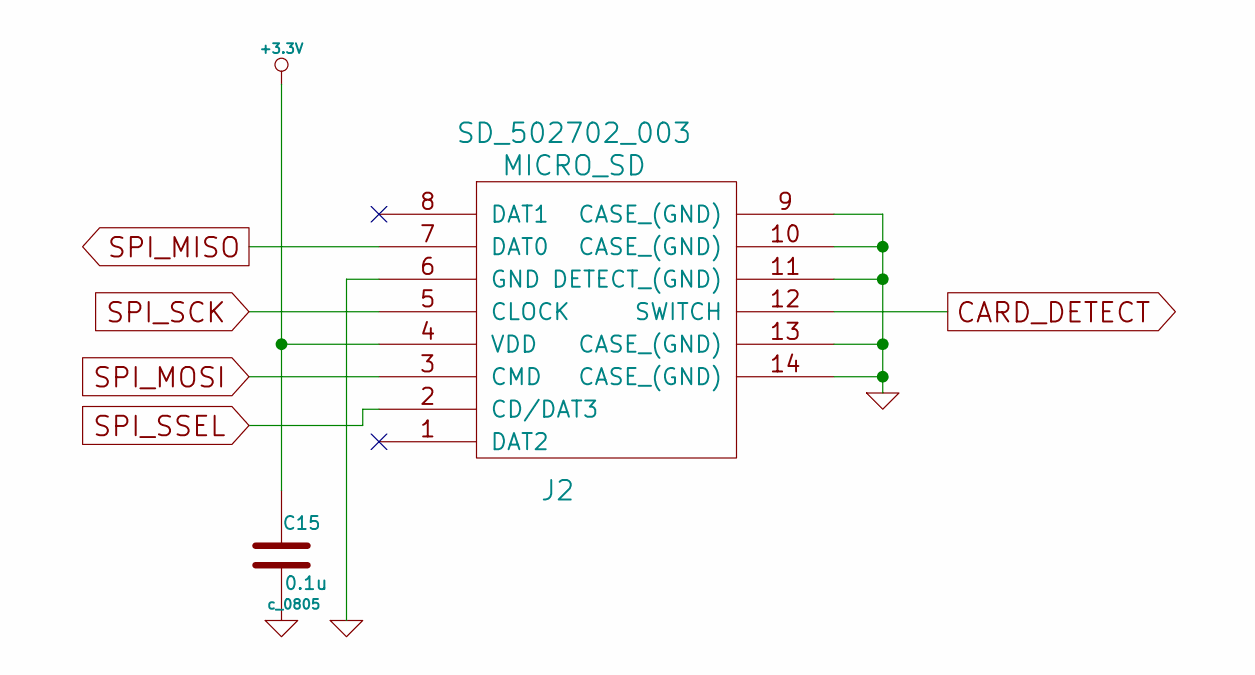
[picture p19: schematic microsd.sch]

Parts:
C15: 0.1u; c_0805
J2: MICRO_SD; SD_502702_003

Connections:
+3.3V: C15.1, J2.4 (VDD); also elsewhere on the board
CARD_DETECT: J2.12 (SWITCH); also elsewhere on the board
GND: C15.2, J2.6 (GND), J2.9 (CASE_(GND)), J2.10 (CASE_(GND)), J2.11 (DETECT_(GND)), J2.13 (CASE_(GND)), J2.14 (CASE_(GND)); also elsewhere on the board
SPI_MISO: J2.7 (DAT0); also elsewhere on the board
SPI_MOSI: J2.3 (CMD); also elsewhere on the board
SPI_SCK: J2.5 (CLOCK); also elsewhere on the board
SPI_SSEL: J2.2 (CD/DAT3); also elsewhere on the board

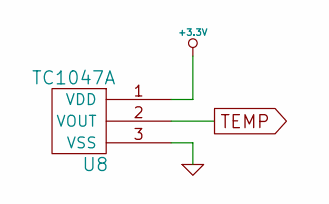
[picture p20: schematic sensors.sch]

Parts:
U8: TC1047A

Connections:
+3.3V: U8.1 (VDD); also elsewhere on the board
GND: U8.3 (VSS); also elsewhere on the board
TEMP: U8.2 (VOUT); also elsewhere on the board

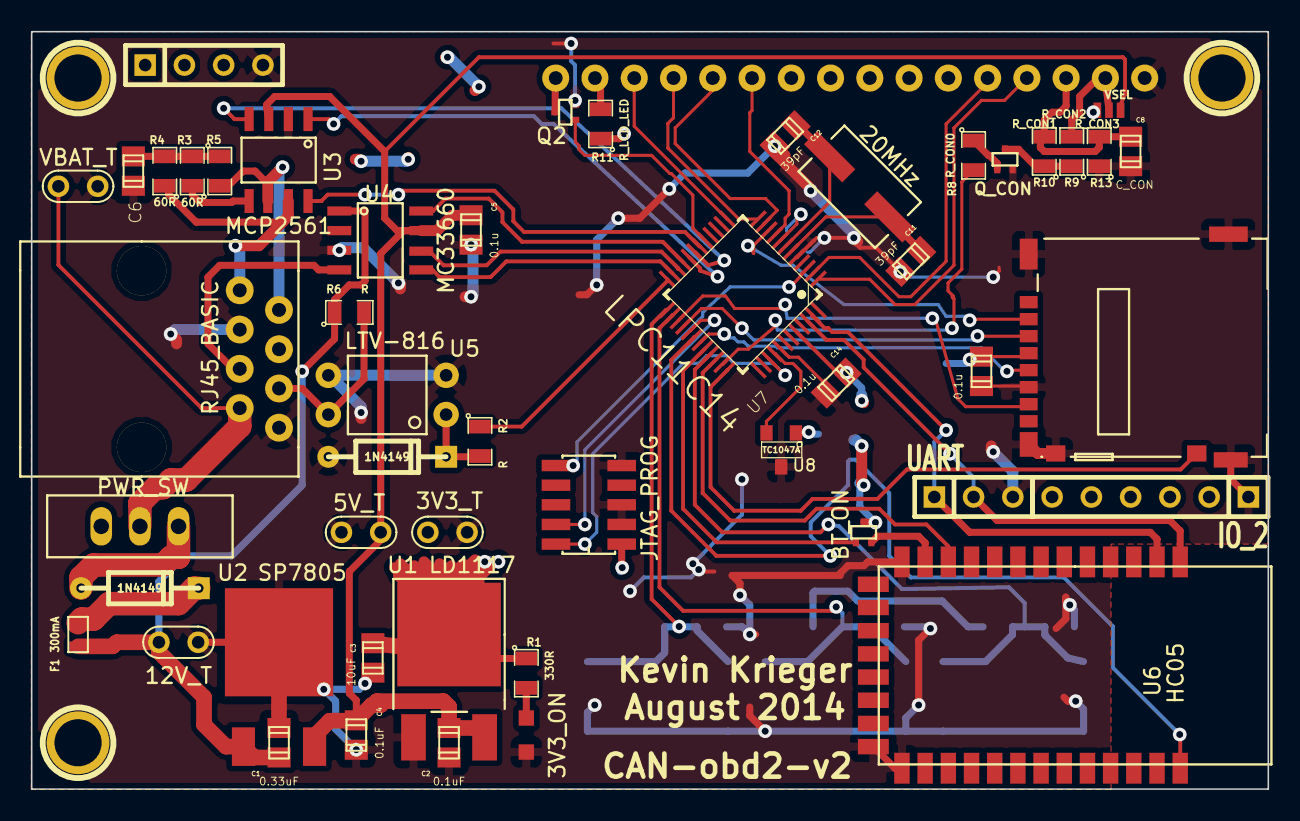
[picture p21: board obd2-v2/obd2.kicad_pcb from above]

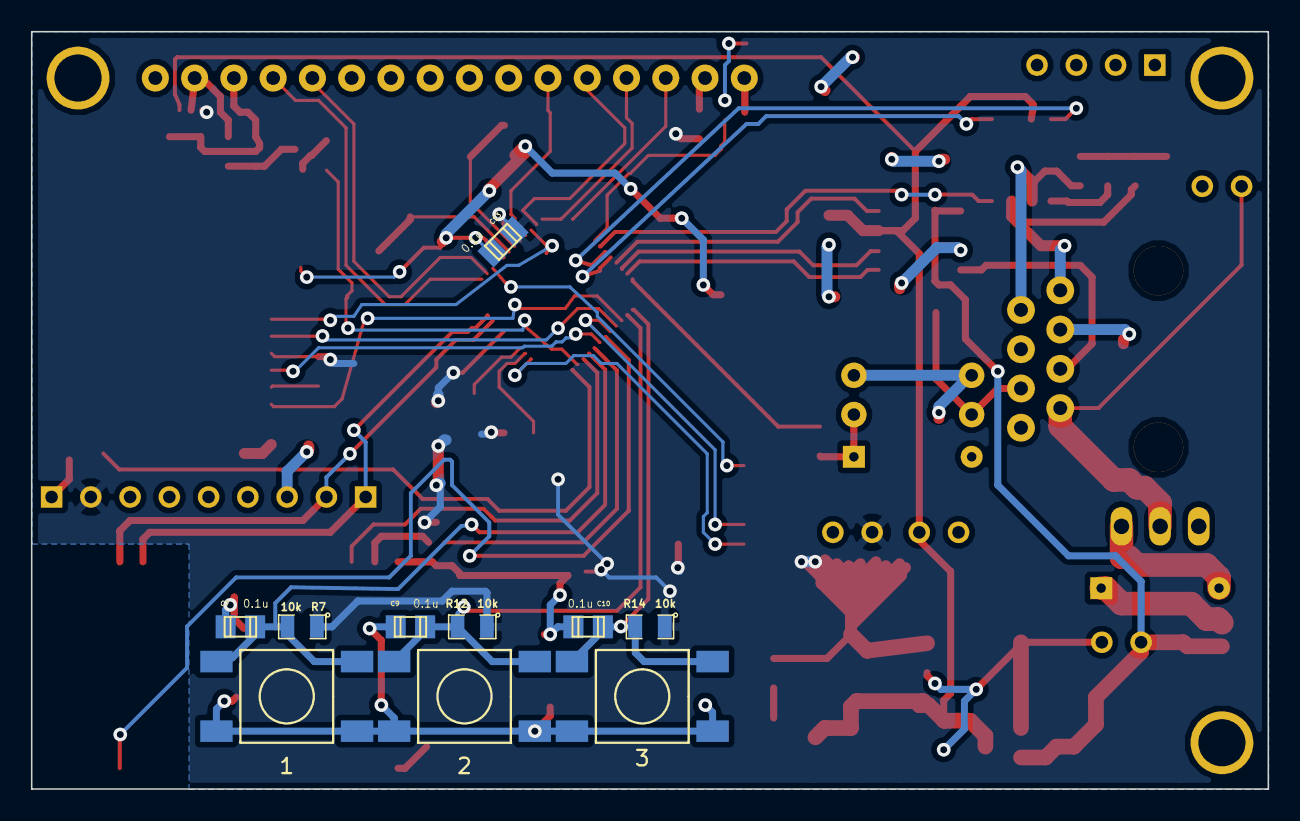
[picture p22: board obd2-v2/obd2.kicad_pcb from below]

Board: 2 copper layers, 80.0 x 49.0 mm, 64 parts (11 on the bottom side), 56 nets.

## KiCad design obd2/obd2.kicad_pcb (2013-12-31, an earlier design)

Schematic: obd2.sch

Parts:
C1: 0.33uF
C2, C3: 0.1uF
C4, C5: 39pF
C6: 10uF
C7, C8, C9, C10: 0.1u
C11: C
C12, C13: 1u
D1: 3V3_ON
D2: 1N4149
F1: approx 300mA
J1: RJ45_BASIC
J2: MICRO_SD
JP1: LCD_V_SELECT
JP2: K_LINE
JP3: L_LINE
JP4: SCS
K1: UART
LCD1: LCD16X2
LCD2: LCD_COG
MP1, MP2, MP3, MP4: SCREW_4-40
P1: JTAG_PROG
P2: IO_1
P3: IO_2
R1: 330R
R2: R
R3, R4: 60 Ohm
R5: 4k7
R6, R7, R8: 10k
R9: R_LCD_LED
R10: R_CON1
R11: R_CON2
SW1, SW2, SW3: SW_OFF_MOM
SW4: PWR_SW
U1: SP7805
U2: LM335
U3: LD1117
U4: LPC11C14
U5: MCP2561
W1: VBAT_T
W2: 5V_T
W3: 3V3_T
W4: 12V_T
X1: 20MHz

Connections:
+3.3V: C6.1, C7.1, C8.1, C10.1, J2.4 (VDD), JP1.1, LCD2.7 (VDD), P1.1, P3.2, R1.1, R6.1, R7.1, R8.1, R9.1, U3.2 (Vout), U4.8 (VDD), U4.44 (VDD), W3.1
+5V: C2.1, C3.1, C9.1, JP1.3, R5.1, U1.3 (Vout), U3.3 (Vin), U5.3 (VDD), W2.1
+12V: C1.1, F1.1, U1.1 (Vin), W4.1
Button1: R6.2, SW1.2, U4.18 (PIO2_4); also elsewhere on the board
Button2: R7.2, SW2.2, U4.21 (PIO2_5); also elsewhere on the board
Button3: R8.2, SW3.2, U4.24 (PIO2_9); also elsewhere on the board
CAN_H: J1.1, R3.1, U5.7 (CANH)
CAN_L: J1.2, R4.2, U5.6 (CANL)
CAN_RXD: U4.19 (CAN_RXD), U5.4 (RXD)
CAN_TXD: U4.20 (CAN_TXD), U5.1 (TXD)
CAN_XCVR_RS: U4.48 (PIO3_3/RI_N), U5.8 (RS)
CARD_DETECT: J2.12 (SWITCH), U4.25 (PIO2_10)
GND: C1.2, C2.2, C3.2, C4.1, C5.1, C6.2, C7.2, C8.2, C9.2, C10.2, C11.1, C12.1, D1.2 (K), J1.3, J1.8, J2.6 (GND), J2.9 (CASE_(GND)), J2.10 (CASE_(GND)), J2.11 (DETECT_(GND)), J2.13 (CASE_(GND)), J2.14 (CASE_(GND)), K1.3, LCD1.1 (VSS), LCD1.16 (LED-), LCD2.6 (VSS), LCD2.12 (LED-), P1.3, P1.5, P1.9, P2.4, P3.1, R11.1, SW1.1, SW2.1, SW3.1, U1.2 (GND), U2.1, U3.1 (GND), U4.5 (VSS), U4.41 (VSS), U5.2 (VSS), W1.2, W2.2, W3.2, W4.2; also elsewhere on the board
K_LINE: J1.5, JP2.1
LCD_DB4/SCL: LCD1.11 (DB4), LCD2.2 (RS), U4.36 (PIO3_0/DTR_N)
LCD_DB5/RST: LCD1.12 (DB5), LCD2.1 (RST), U4.37 (PIO3_1/DSR_N)
LCD_DB6: LCD1.13 (DB6), U4.43 (PIO3_2/DCD_N)
LCD_DB7: LCD1.14 (DB7), U4.45 (PIO1_5/RTS_N/CT32B0_CAP0)
LCD_E/CSB: LCD1.6 (E), LCD2.3 (CSB), U4.35 (R/PIO1_2/AD3/CT32B1_MAT1)
LCD_RS/SI: LCD1.4 (RS), LCD2.5 (SI), U4.33 (R/PIO1_0/AD1/CT32B1_CAP0)
LCD_RW/RS: LCD1.5 (RW), LCD2.4 (SCL), U4.34 (R/PIO1_1/AD2/CT32B1_MAT0)
L_LINE: J1.6, JP3.1
unnamed: C4.2, U4.6 (XTALIN), X1.1
unnamed: C5.2, U4.7 (XTALOUT), X1.2, X1.4
unnamed: D2.1 (A), SW4.1
unnamed: JP4.2, P2.3, U4.1 (PIO2_6)
unnamed: JP3.2, P2.2, U4.2 (PIO2_0/DTR_N/SSEL1)
unnamed: JP2.2, P2.1, U4.4 (PIO0_1/CLKOUT/CT32B0_MAT2)
unnamed: P3.3, U4.17 (PIO1_9/CT16B1_MAT0)
unnamed: P3.5, U4.15 (PIO0_4/SCL)
unnamed: P3.4, U4.16 (PIO0_5/SDA)
unnamed: P3.6, U4.14 (PIO0_3)
unnamed: JP1.2, LCD1.2 (VDD), R10.2
unnamed: LCD1.15 (LED+), LCD2.11 (LED+), R9.2
unnamed: C12.2, LCD2.8 (VOUT)
unnamed: C13.2, LCD2.10 (C1-)
unnamed: C13.1, LCD2.9 (C1+)
unnamed: D1.1 (A), R1.2
unnamed: R2.1, U5.5 (SPLIT)
unnamed: C11.2, R2.2, R3.2, R4.1
unnamed: D2.2 (K), F1.2
unnamed: LCD1.3 (V0), R10.1, R11.2
SCS: J1.4, JP4.1
SPI_MISO: J2.7 (DAT0), U4.27 (PIO0_8/MISO0/CT16B0_MAT0)
SPI_MOSI: J2.3 (CMD), U4.28 (PIO0_9/MOSI0/CT16B0_MAT1)
SPI_SCK: J2.5 (CLOCK), U4.31 (PIO2_11/SCK0)
SPI_SSEL: J2.2 (CD/DAT3), U4.10 (PIO0_2/SSEL0/CT16B0_CAP0)
SWCLK: P1.4, U4.29 (SWCLK/PIO0_10/SCK0/CT16B0_MAT2)
SWDIO: P1.2, U4.39 (SWDIO/PIO1_3/AD4/CT32B1_MAT2)
TEMP: R5.2, U2.2, U4.42 (PIO1_11/AD7)
UART_RXD: K1.2 (PM), U4.46 (PIO1_6/RXD/CT32B0_MAT0)
UART_TXD: K1.1, U4.47 (PIO1_7/TXD/CT32B0_MAT1)
VBAT: J1.7, SW4.2, W1.1
~RESET: P1.10, U4.3 (RESET_N/PIO0_0)

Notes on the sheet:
XTAL required if C_CAN baud rates above 100kbit/s used
Mounting holes 4-40 hardware
Option for one of two types of LCD screen
Micro-SD circuitry
CAN transceiver circuitry
Sensor circuitry
OBD2 connection DLC - Diagnostic Link Connector in Honda Civic
User input
1 2 3 4 5 6 7 8 9 10 11 12 13 14 15 16
4 - Chassis Ground 5 - Signal Ground 6 - CAN high (J-2284) 7 - K-LINE (ISO 9141-2 and ISO/DIS 14230-4) 9 - SCS - (Service Check System - diagnostic codes) 14 - CAN low 15 - ISO 9141-2 L-Line (ISO 9141-2 and ISO/DIS 14230-4) 16 - +12V unswitched
R_CON1 and R_CON2 set contrast. R_LCD_LED sets LCD backlight brightness (10-30ohm)
VBAT is unswitched battery voltage +12V is switched/diode/fused +5V/+3.3V are regulated voltages

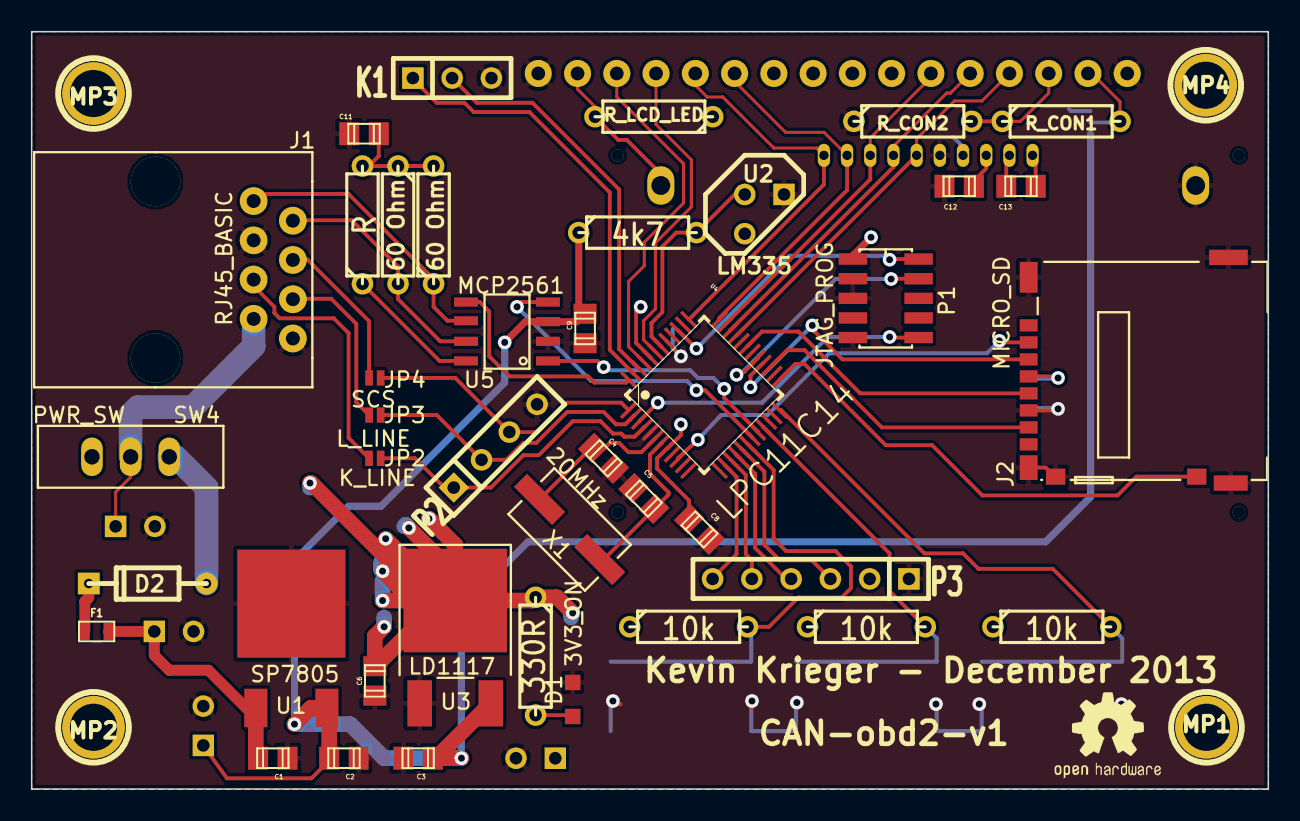
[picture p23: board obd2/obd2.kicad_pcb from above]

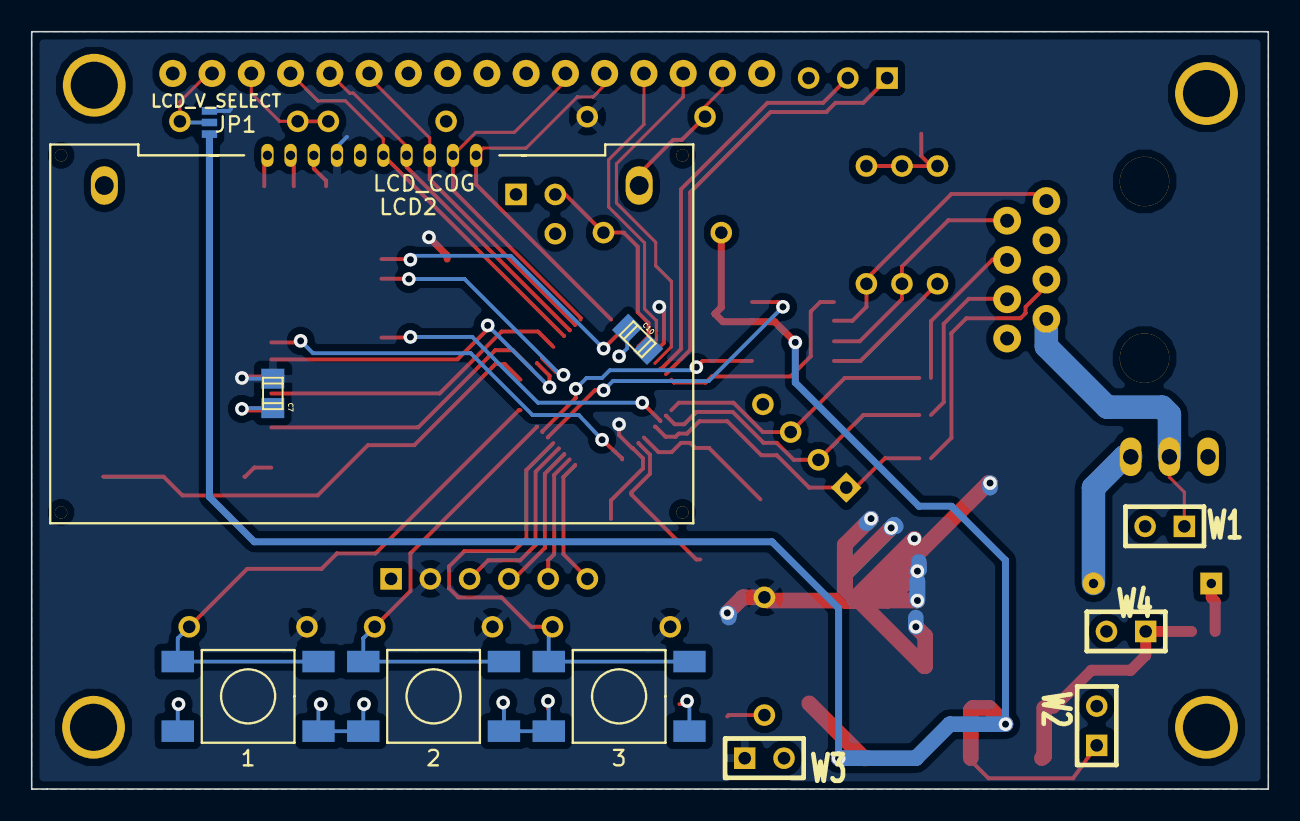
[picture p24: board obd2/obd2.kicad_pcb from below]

Board: 2 copper layers, 80.0 x 49.0 mm, 57 parts (12 on the bottom side), 54 nets.

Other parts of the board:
1, 2, 3: SW_OFF_MOM; FSM4JSMA_pushbutton

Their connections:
Button1: 3.2; also elsewhere on the board
Button2: 2.2; also elsewhere on the board
Button3: 1.2; also elsewhere on the board
GND: 1.1, 2.1, 3.1; also elsewhere on the board

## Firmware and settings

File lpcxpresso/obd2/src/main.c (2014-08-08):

/*
===============================================================================
 Name        : main.c
 Author      : $(author)
 Version     :
 Copyright   : $(copyright)
 Description : main definition
===============================================================================
*/

#if defined (__USE_LPCOPEN)
#include "board.h"
#endif
#include <stdio.h>
#include <cr_section_macros.h>
#include <string.h>
#include "systick.h"
#include "ccan_rom.h"
#include "ring_buffer.h"
#include "cmds.h"

#define TICKRATE_HZ1 10
int i = 0;
int j = 0;
int read_character = EOF;
uint8_t rb_itemSize = 1;
#define RB_LEN	256
uint8_t rb_data[RB_LEN];
static RINGBUFF_T ringbuffer;

/**
 * @brief	Handle interrupt from 32-bit timer
 * @return	Nothing
 */
void TIMER32_0_IRQHandler(void)
{

	if (Chip_TIMER_MatchPending(LPC_TIMER32_0, 1)) {
		i++;
		Chip_TIMER_ClearMatch(LPC_TIMER32_0, 1);
		if( Board_LED_Test(1)) {
			Board_LED_Set(1, 0);
		}
		else {
			Board_LED_Set(1, 1);
		}
	}
	if(i % 20 == 0) {
		j=j+1;
		//Board_UARTPutChar('t');
		//DEBUGSTR(" Test 0123456789.`~!@#$%^&*()-=_+[]{}\\|;:/?.>,<");
		//read_character = DEBUGIN();
		//while(read_character != EOF) {
		//	Board_UARTPutChar(read_character);
		//	read_character = DEBUGIN();
		//}
	//	while(RingBuffer_Pop(&ringbuffer, &read_character)) {
	//		Board_UARTPutChar(read_character);
		//}
		//read_character = DEBUGIN();
		//while(read_character != EOF) {
	//		Board_UARTPutChar(read_character);
		//	read_character = DEBUGIN();
	//	}
	//	DEBUGSTR("Temperature value: %d\r\n", Board_Get_Temperature());
		/* Send a message on CAN bus to query 7DF (see http://en.wikipedia.org/wiki/OBD-II_PIDs#CAN_.2811-bit.29_Bus_format)
			 * Message objects 1 and 2 should receive from 7E8 as an example, really they should have masks set to receive
			 * from 7E8 to 7EF. this is a TODO  */
			msg_obj.msgobj  = 3;
			msg_obj.mode_id = 0x7df | CAN_MSGOBJ_EXT;
			msg_obj.mask    = 0x0;
			msg_obj.dlc     = 8;
	/* SAE standard says that the 8 bytes should look like so for a query on 7DF:
	 * 0 = 2 for number of additional data bytes
	 * 1 = mode (1 for current data and 2 for freeze frame, meaning the last saved state when 'check engine' was lit up)
	 * 2 = PID code (0x0c should be engine rpm (again see http://en.wikipedia.org/wiki/OBD-II_PIDs#Mode_01 ) which returns
	 * two bytes that are interpreted as : rpm = ((A*256)+B)/4
	 */
			msg_obj.data[0] = 0x02; // 2 == 2 additional data bytes
			msg_obj.data[1] = 0x01; // 1 == current frame
			//msg_obj.data[2] = 0x0c; //engine rpm = (A*256 + B) / 4
			//msg_obj.data[2] = 0x0d; //speed km/hr
		//	msg_obj.data[2] = j%31; //increment
			msg_obj.data[2] = 0; //which pids are supported? 0x00 to 0x20?
			msg_obj.data[3] = 0x55;
			msg_obj.data[4] = 0x55;
			msg_obj.data[5] = 0x55;
			msg_obj.data[6] = 0x55;
			msg_obj.data[7] = 0x55;

			LPC_CCAN_API->can_transmit(&msg_obj);
	}
}

void UART_IRQHandler (void){
	//DEBUGSTR("Yep\r\n");
	if(LPC_USART->IIR & UART_IIR_INTID_RDA) {
		DEBUGSTR("RDA\r\n\x00");
		/* New data will be ignored if data not popped in time */
		while (Chip_UART_ReadLineStatus(LPC_USART) & UART_LSR_RDR) {
			uint8_t ch = Chip_UART_ReadByte(LPC_USART);
			RingBuffer_Insert(&ringbuffer, &ch);
			DEBUGSTR("inserted char into ringbuffer\r\n\x00");
			//Chip_UART_SendByte(LPC_USART, ch);
			//DEBUGSTR("\r\n"\x00);
		}
		hdlc_frame_parser(&ringbuffer);
	} else if(LPC_USART->IIR & UART_IIR_INTID_RLS) {
	//	DEBUGSTR("Yep");
		DEBUGSTR("RLS\r\n\x00");
		Chip_UART_RXIntHandlerRB(LPC_USART, &ringbuffer);
	}
	else {
		DEBUGSTR("UNKNOWN\r\n\x00");
		//DEBUGSTR("Unknown\r\n");
	}
}


int main(void) {
#if defined (__USE_LPCOPEN)
#if !defined(NO_BOARD_LIB)
    // Read clock settings and update SystemCoreClock variable
    SystemCoreClockUpdate();
    // Set up and initialize all required blocks and
    // functions related to the board hardware
    Board_Init();
    // Set the LED to the state of "On"
    Board_LED_Set(1, true);
#endif
#endif

    uint32_t timerFreq;
    /* Initialize ring buffer */
    RingBuffer_Init(&ringbuffer, rb_data, rb_itemSize, RB_LEN);

	/* Enable timer 1 clock */
	Chip_TIMER_Init(LPC_TIMER32_0);

	/* Timer rate is system clock rate */
	timerFreq = Chip_Clock_GetSystemClockRate();



	/* Timer setup for match and interrupt at TICKRATE_HZ */
	Chip_TIMER_Reset(LPC_TIMER32_0);
	Chip_TIMER_MatchEnableInt(LPC_TIMER32_0, 1);
	Chip_TIMER_SetMatch(LPC_TIMER32_0, 1, (timerFreq / TICKRATE_HZ1));
	Chip_TIMER_ResetOnMatchEnable(LPC_TIMER32_0, 1);
	Chip_TIMER_Enable(LPC_TIMER32_0);

	/* Enable timer interrupt */
	NVIC_ClearPendingIRQ(TIMER_32_0_IRQn);
	NVIC_EnableIRQ(TIMER_32_0_IRQn);

	/* LEDs toggle in interrupt handlers */
	Chip_GPIO_SetPinDIROutput(LPC_GPIO, 2, 6);

    uint32_t CanApiClkInitTable[2];
	/* Publish CAN Callback Functions */
	CCAN_CALLBACKS_T callbacks = {
		CAN_rx,
		CAN_tx,
		CAN_error,
		NULL,
		NULL,
		NULL,
		NULL,
		NULL,
	};
	baudrateCalculate(TEST_CCAN_BAUD_RATE, CanApiClkInitTable);

	LPC_CCAN_API->init_can(&CanApiClkInitTable[0], TRUE);
	/* Configure the CAN callback functions */
	LPC_CCAN_API->config_calb(&callbacks);
	/* Enable the CAN Interrupt */
	NVIC_EnableIRQ(CAN_IRQn);
	NVIC_EnableIRQ(UART0_IRQn);
//LPC_CAN0->CANTEST |= 0b10000;

	/* Send a simple one time CAN message */
/*	msg_obj.msgobj  = 0;
	msg_obj.mode_id = 0x3FF | CAN_MSGOBJ_EXT;
	msg_obj.mask    = 0x0;
	msg_obj.dlc     =8;
	msg_obj.data[0] = 'b';	// 0x54
	msg_obj.data[1] = 'E';	// 0x45
	msg_obj.data[2] = 'S';	// 0x53
	msg_obj.data[3] = 'T';	// 0x54
	msg_obj.data[4] = 'b';	// 0x54
	msg_obj.data[5] = 'u';	// 0x45
	msg_obj.data[6] = 'd';	// 0x53
	msg_obj.data[7] = 's';	// 0x54

	LPC_CCAN_API->can_transmit(&msg_obj);
*/
/*	msg_obj.msgobj  = 0;
	msg_obj.mode_id = 0x7df;
	msg_obj.mask    = 0x0;
	msg_obj.dlc     = 8;
	msg_obj.data[0] = 0x02;
	msg_obj.data[1] = 0x01;
	msg_obj.data[2] = 0x0c;
	msg_obj.data[3] = 0x00;
	msg_obj.data[4] = 0x00;
	msg_obj.data[5] = 0x00;
	msg_obj.data[6] = 0x00;
	msg_obj.data[7] = 0x00;
*/
	//LPC_CCAN_API->can_transmit(&msg_obj);


	/* Configure message object 1 to receive all extended  messages  */
	msg_obj.msgobj = 1;
	msg_obj.mode_id = 0x7E8UL | CAN_MSGOBJ_EXT;
	msg_obj.mask = 0x0UL;
	LPC_CCAN_API->config_rxmsgobj(&msg_obj);

	/* Configure message object 2 to receive all 11 bit 7E0-7EF messages  */
	msg_obj.msgobj = 2;
	msg_obj.mode_id = 0x7E0;
	//msg_obj.mask = 0x7F0;
	msg_obj.mask = 0x0;//receive everything!
	LPC_CCAN_API->config_rxmsgobj(&msg_obj);


	//Board_LCD_WriteString("Testing!");
	//Board_LCD_cmd(0xC0); // Go to start of second line
	//Board_LCD_WriteString("Woop Woop!");
	while (1) {
		__WFI();
	}

	return 0;
}

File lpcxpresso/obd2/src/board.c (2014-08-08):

/*
 * @brief CAN-obd2 11C14 board file
 *
 * @note
 * Copyright(C) NXP Semiconductors, 2013
 * All rights reserved.
 *
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
 * @par
 * Permission to use, copy, modify, and distribute this software and its
 * documentation is hereby granted, under NXP Semiconductors' and its
 * licensor's relevant copyrights in the software, without fee, provided that it
 * is used in conjunction with NXP Semiconductors microcontrollers.  This
 * copyright, permission, and disclaimer notice must appear in all copies of
 * this code.
 */

#include "board.h"
#include "retarget.h"
#include "systick.h"
#include "ff.h"
#include "rtc.h"
#include "ccan_rom.h"
#include <string.h>
#include "cmds.h"

/*****************************************************************************
 * Private types/enumerations/variables
 ****************************************************************************/

/* SD card/filesystem stuff */
extern const char microSDTestData[1024];
extern const char microRestartedMsg[64];
extern const TCHAR *testfilename;
extern FATFS Fatfs[_VOLUMES];	/* File system object for each logical drive */
extern FIL File[2];				/* File objects */
extern BYTE sdbuffer[1024] __attribute__ ((aligned (4))) ;	/* Working buffer,
this will overflow your bss segment if it is too large. */
UINT s1;


const float adcVref = 3.3; // ADC reference voltage
uint16_t dataADC = 0; // Temporary adc storage
static ADC_CLOCK_SETUP_T ADCSetup;
char lcdBuffer[16];

/*****************************************************************************
 * Public types/enumerations/variables
 ****************************************************************************/

/* System oscillator rate and clock rate on the CLKIN pin */
const uint32_t OscRateIn = 20000000; // CAN-obd2 crystal is 20MHz
const uint32_t ExtRateIn = 0;

/*****************************************************************************
 * Private functions
 ****************************************************************************/

/*****************************************************************************
 * Public functions
 ****************************************************************************/

/* Sends a character on the UART */
void Board_UARTPutChar(char ch)
{
#if defined(DEBUG_UART)
	Chip_UART_SendBlocking(DEBUG_UART, &ch, 1);
#endif
}

/* Gets a character from the UART, returns EOF if no character is ready */
int Board_UARTGetChar(void)
{
#if defined(DEBUG_UART)
	uint8_t data;

	if (Chip_UART_Read(DEBUG_UART, &data, 1) == 1) {
		return (int) data;
	}
#endif
	return EOF;
}

/* Outputs a string on the debug UART */
void Board_UARTPutSTR(char *str)
{
#if defined(DEBUG_UART)
	while (*str != '\0') {
		Board_UARTPutChar(*str++);
	}
#endif
}

/* Initialize debug output via UART for board */
void Board_Debug_Init(void)
{
#if defined(DEBUG_UART)
	Chip_IOCON_PinMuxSet(LPC_IOCON, IOCON_PIO1_6, (IOCON_FUNC1 | IOCON_MODE_INACT)); /* RXD ** VERIFIED CORRECT on CAN-obd2 v1** */
	Chip_IOCON_PinMuxSet(LPC_IOCON, IOCON_PIO1_7, (IOCON_FUNC1 | IOCON_MODE_INACT)); /* TXD ** VERIFIED CORRECT on CAN-obd2 v1** */

	/* Setup UART for 115.2K8N1 and receive RBR interrupt */
	Chip_UART_Init(LPC_USART);
	Chip_UART_SetBaud(LPC_USART, 9600);
	Chip_UART_ConfigData(LPC_USART, (UART_LCR_WLEN8 | UART_LCR_SBS_1BIT | UART_LCR_PARITY_DIS));
	Chip_UART_SetupFIFOS(LPC_USART, (UART_FCR_FIFO_EN | UART_FCR_RX_RS | UART_FCR_TX_RS | UART_FCR_TRG_LEV3));
	Chip_UART_IntEnable(LPC_USART,(UART_IER_RBRINT | UART_IER_RLSINT));
	Chip_UART_TXEnable(LPC_USART);

#endif
}

/* Initialize the us tick timer */
static void Board_us_Init(void) {
	/* Timer setup for 1us tickrate */
	Chip_TIMER_Init(LPC_TIMER32_1);
	Chip_TIMER_Reset(LPC_TIMER32_1);
	Chip_TIMER_PrescaleSet(LPC_TIMER32_1, (Chip_Clock_GetSystemClockRate()/1000000));
	Chip_TIMER_Enable(LPC_TIMER32_1);
}

/* Initializes board LED(s) */
static void Board_LED_Init(void)
{
	/* Set the PIO0_3 as output on CAN-obd2 v1. Also available are PIO0_4 and 5, and PIO1_9 */
	Chip_GPIO_SetPinDIROutput(LPC_GPIO, 0, 3);
	Chip_GPIO_SetPinState(LPC_GPIO, 0, 3, 0);
	Chip_GPIO_SetPinDIROutput(LPC_GPIO, 0, 4);/* GPIO_0_4 is OPEN DRAIN */
	Chip_GPIO_SetPinDIROutput(LPC_GPIO, 0, 5);/* GPIO_0_5 is OPEN DRAIN */
	Chip_GPIO_SetPinDIROutput(LPC_GPIO, 1, 9);
}

/* Initialize input pushbuttons */
static void Board_Pushbutton_Init(void) {
	/* Set input directions */
	Chip_GPIO_SetPinDIRInput(LPC_GPIO, 2, 4);
	Chip_GPIO_SetPinDIRInput(LPC_GPIO, 2, 5);
	Chip_GPIO_SetPinDIRInput(LPC_GPIO, 2, 9);

	/* Enable Pullups */
	Chip_IOCON_PinMuxSet(LPC_IOCON, IOCON_PIO2_4, (IOCON_FUNC0 | IOCON_MODE_PULLUP));
	Chip_IOCON_PinMuxSet(LPC_IOCON, IOCON_PIO2_5, (IOCON_FUNC0 | IOCON_MODE_PULLUP));
	Chip_IOCON_PinMuxSet(LPC_IOCON, IOCON_PIO2_9, (IOCON_FUNC0 | IOCON_MODE_PULLUP));

	/* Enable and configure interrupts on falling edge */
	Chip_GPIO_SetPinModeEdge(LPC_GPIO, 2, (0b1000110000));
	Chip_GPIO_SetEdgeModeSingle(LPC_GPIO, 2, (0b1000110000));
	Chip_GPIO_SetModeLow(LPC_GPIO, 2, (0b1000110000));
	Chip_GPIO_EnableInt(LPC_GPIO, 2, (0b1000110000));

	/* Enable interrupt in the NVIC */
	NVIC_ClearPendingIRQ(EINT2_IRQn);
	NVIC_EnableIRQ(EINT2_IRQn);
}

/* Initialize the onboard temperature sensor */
static void Board_Temperature_Init(void) {
	/* Initialize the adc channel */
	Chip_IOCON_PinMuxSet(LPC_IOCON, IOCON_PIO1_11, (IOCON_FUNC1 | IOCON_ADMODE_EN));
	Chip_ADC_Init(LPC_ADC, &ADCSetup);
	Chip_ADC_EnableChannel(LPC_ADC, ADC_CH7, ENABLE);
}

/* Strobe the LCD EN line */
void Board_LCD_Strobe(void)
{
    Chip_GPIO_SetPinState(LPC_GPIO, 1, 2, 1);
    __delay_us(1);
    Chip_GPIO_SetPinState(LPC_GPIO, 1, 2, 0);
}

/**
 * @brief	Write to the LCD screen a character
 * @param	Character : a character to write to LCD screen
 * @return	None
 * */
void Board_LCD_WriteChar(char c) {
	Chip_GPIO_SetPinState(LPC_GPIO, 1, 0, 1);
    __delay_us(50);
    Chip_GPIO_SetPinState(LPC_GPIO, 1, 5, (c & 0x80));
    Chip_GPIO_SetPinState(LPC_GPIO, 3, 2, (c & 0x40));
    Chip_GPIO_SetPinState(LPC_GPIO, 3, 1, (c & 0x20));
    Chip_GPIO_SetPinState(LPC_GPIO, 3, 0, (c & 0x10));
    Board_LCD_Strobe();

    Chip_GPIO_SetPinState(LPC_GPIO, 1, 5, (c & 0x08));
    Chip_GPIO_SetPinState(LPC_GPIO, 3, 2, (c & 0x04));
    Chip_GPIO_SetPinState(LPC_GPIO, 3, 1, (c & 0x02));
    Chip_GPIO_SetPinState(LPC_GPIO, 3, 0, (c & 0x01));
    Board_LCD_Strobe();
}

/**
 * @brief	Write string to the LCD screen
 * @param	String : a string to write to the LCD screen
 * @return	None
 * 1  2  3  4  5  6  7  8  9  10 11 12 13 14 15 16
 * 00 01 02 03 04 05 06 07 08 09 0A 0B 0C 0D 0E 0F
 * 40 41 42 43 44 45 46 47 48 49 4A 4B 4C 4D 4E 4F
 */
void Board_LCD_WriteString(const char * lcdstring) {
	while (*lcdstring) {
		Board_LCD_WriteChar(*lcdstring++);
	}
}
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

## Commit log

2013-11-08 Initial commit.
    [obd2.kicad_pcb, obd2.sch]
2013-11-08 Added new kicad project for old design with lpc1343
    [obd2_lpc1343.kicad_pcb, obd2_lpc1343.sch]
2013-11-14 Moved some files around.
    [obd2.kicad_pcb, obd2.sch]
2013-11-26 Automotive power protection reference
2013-11-26 Almost done schematic and component selections
    [obd2.kicad_pcb, obd2.sch]
2013-12-06 Added datasheets for diode/fuses/power switch
2013-12-06 All signals routed but power
    [obd2.kicad_pcb, obd2.sch]
2013-12-14 Routed power and added port for UART. Added logos.
    [obd2.csv, obd2.kicad_pcb, obd2.sch]
2013-12-16 Added schematic and copper printouts in ps, pdf format
2013-12-31 Moved components to add enough room for 4-40 hardware. Moved all silkscreen values to appropriate places. rev 1 finished and ordered.
    [obd2-B_Cu.gbl, obd2-B_Mask.gbs, obd2-B_SilkS.gbo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]
2014-01-23 Rearranged structure. added images.
    [obd2.sch]
2014-03-05 Added gitignore, added lpc usermanual, added BOM with comments
    [obd2.csv, obd2.ods, obd2.sch]
2014-05-15 Change comments to further explain button 1 interrupt CAN message. Change default CAN speed to 250kHz.
2014-08-08 Added timer functions
2014-08-08 Added timeout timer and fixed bugs in hdlc
    [cmds.c]
2014-08-08 Fixed bug in hdlc
    [cmds.c]
2014-08-26 New revision fixing multiple footprint issues, adding bt module, smaller temp sensor and K-line txvr among other things.
    [microcontroller.sch, microsd.sch, obd2.csv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]
